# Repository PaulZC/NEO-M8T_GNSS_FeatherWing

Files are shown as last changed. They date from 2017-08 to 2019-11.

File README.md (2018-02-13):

# NEO-M8T GNSS FeatherWing

A clone of the [Adafruit Ultimate GPS FeatherWing](https://www.adafruit.com/product/3133) but with the u-blox NEO-M8T replacing the GlobalTop FGPMMOPA6H. The NEO-M8T can receive signals from GPS, Galileo and GLONASS or BeiDou concurrently and supports both SBAS and QZSS.
It also provides Multi-GNSS Raw Measurement (RAWX) Data which can be used for Post-Processed Kinematic (PPK) positioning.

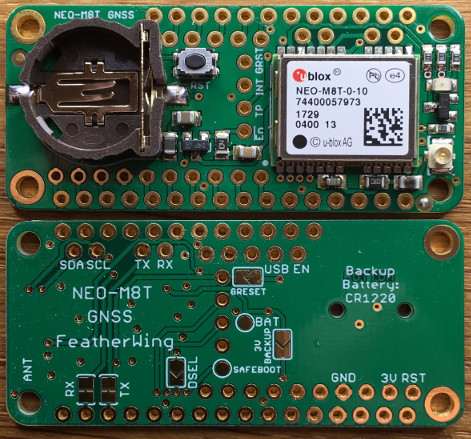
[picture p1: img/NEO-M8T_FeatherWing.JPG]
NEO-M8T_FeatherWing


**See [LEARN.md](https://github.com/PaulZC/NEO-M8T_GNSS_FeatherWing/blob/master/LEARN.md) for more details.**

[POST_PROCESS.md](https://github.com/PaulZC/NEO-M8T_GNSS_FeatherWing/blob/master/POST_PROCESS.md) contains results of a first time successful attempt at post-processed kinematic positioning using [rtkexplorer's demo5 version of RTKLIB](http://rtkexplorer.com/downloads/rtklib-code/).

See [NEO-M8T_GNSS_FeatherWing.pdf](https://github.com/PaulZC/NEO-M8T_GNSS_FeatherWing/blob/master/NEO-M8T_GNSS_FeatherWing.pdf) for the schematic, layout and Bill Of Materials.

The [Eagle](https://github.com/PaulZC/NEO-M8T_GNSS_FeatherWing/tree/master/Eagle) directory contains the schematic and pcb design files.

The [Arduino](https://github.com/PaulZC/NEO-M8T_GNSS_FeatherWing/tree/master/Arduino) directory contains code for the [Adafruit Feather M0 Adalogger](https://www.adafruit.com/products/2796) which will log RAWX data to SD card.

Distributed under a Creative Commons Attribution, Share-Alike license.

Enjoy!

**_Paul_**

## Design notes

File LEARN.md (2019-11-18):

# NEO-M8T GNSS FeatherWing

A clone of the [Adafruit Ultimate GPS FeatherWing](https://www.adafruit.com/product/3133) but with the u-blox NEO-M8T replacing the GlobalTop FGPMMOPA6H. The NEO-M8T can receive signals from GPS, Galileo and either GLONASS or BeiDou concurrently and supports both SBAS and QZSS.
It also provides Multi-GNSS Raw Measurement (RAWX) Data which can be used for Post-Processed Kinematic (PPK) positioning.

NEO-M8T_FeatherWing

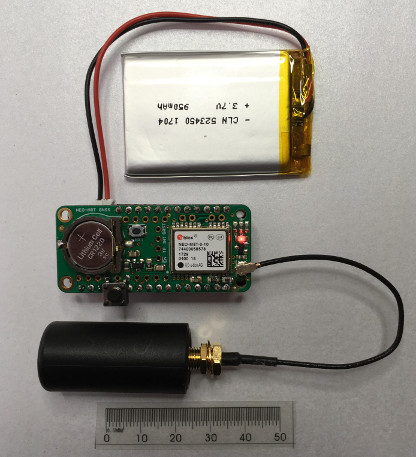
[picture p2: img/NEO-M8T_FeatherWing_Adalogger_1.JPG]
NEO-M8T_FeatherWing_Adalogger_1


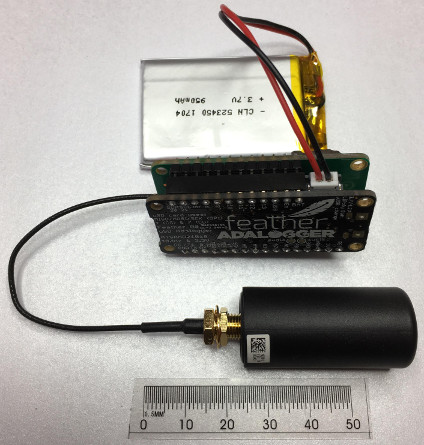
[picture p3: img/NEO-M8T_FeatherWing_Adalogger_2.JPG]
NEO-M8T_FeatherWing_Adalogger_2


See [NEO-M8T_GNSS_FeatherWing.pdf](https://github.com/PaulZC/NEO-M8T_GNSS_FeatherWing/blob/master/NEO-M8T_GNSS_FeatherWing.pdf) for the schematic, layout and Bill Of Materials.

The [Eagle](https://github.com/PaulZC/NEO-M8T_GNSS_FeatherWing/tree/master/Eagle) directory contains the schematic and PCB design files.

The [SMA_Antenna](https://github.com/PaulZC/NEO-M8T_GNSS_FeatherWing/tree/master/Eagle/SMA_Antenna) directory contains the schematic and PCB design files for an extended
version of the PCB which incorporates a robust SMA connector for the antenna instead of uFL.

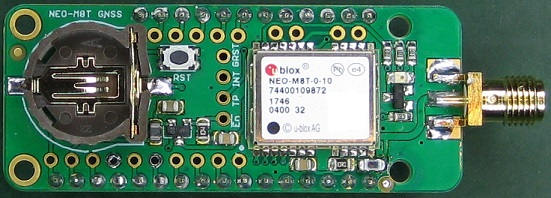
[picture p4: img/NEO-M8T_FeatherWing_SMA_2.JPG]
NEO-M8T_FeatherWing_SMA_2


The [Arduino](https://github.com/PaulZC/NEO-M8T_GNSS_FeatherWing/tree/master/Arduino) directory contains code for the [Adafruit Feather M0 Adalogger](https://www.adafruit.com/products/2796) which will log RAWX data to SD card.
- https://www.adafruit.com/products/2796
- https://learn.adafruit.com/adafruit-feather-m0-adalogger

[POST_PROCESS.md](https://github.com/PaulZC/NEO-M8T_GNSS_FeatherWing/blob/master/POST_PROCESS.md) contains results of a first time successful attempt at post-processed kinematic positioning using [rtkexplorer's demo5 version of RTKLIB](http://rtkexplorer.com/downloads/rtklib-code/).
Please refer to the [Precise Positioning Resources](https://github.com/PaulZC/NEO-M8T_GNSS_FeatherWing/blob/master/LEARN.md#precise-positioning-resources) for more information.

This guide concentrates on the differences between the NEO-M8T FeatherWing and the Adafruit Ultimate GPS FeatherWing. Please refer to Lady Ada's excellent documentation to get started with the Feather family and GPS:
- https://www.adafruit.com/product/3133
- https://learn.adafruit.com/adafruit-ultimate-gps-featherwing

## Power Pins

Like the Ultimate GPS FeatherWing, the NEO-M8T FeatherWing runs from +3.3V power and uses 3V logic. The NEO-M8T is powered directly from the 3V and GND pins on the bottom left of the Feather. Each Adafruit Feather has a regulator to provide clean 3V power from USB or battery power.

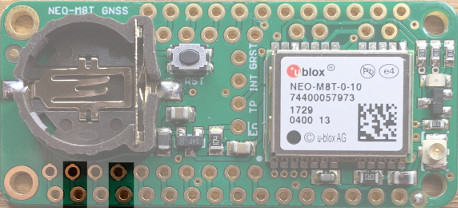
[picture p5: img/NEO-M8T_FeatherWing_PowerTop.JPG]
NEO-M8T_FeatherWing_PowerTop


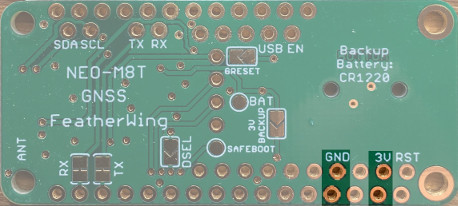
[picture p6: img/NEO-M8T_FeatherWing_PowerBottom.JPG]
NEO-M8T_FeatherWing_PowerBottom


If you want to completely power down the Adalogger _and_ the NEO-M8T, you can do this by pulling the Feather EN pin low (e.g. by connecting it to GND via a small slide switch).

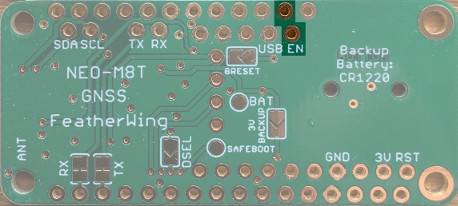
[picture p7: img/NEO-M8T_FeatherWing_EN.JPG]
NEO-M8T_FeatherWing_EN


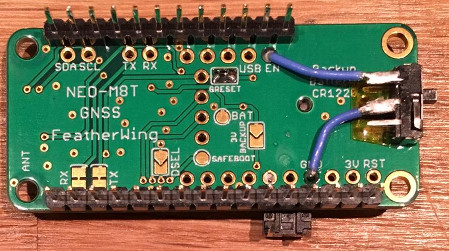
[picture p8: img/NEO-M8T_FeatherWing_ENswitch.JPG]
NEO-M8T_FeatherWing_ENswitch


## Serial Data Pins

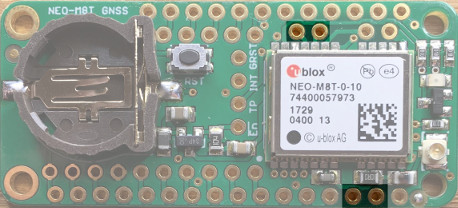
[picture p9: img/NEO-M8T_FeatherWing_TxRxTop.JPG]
NEO-M8T_FeatherWing_TxRxTop


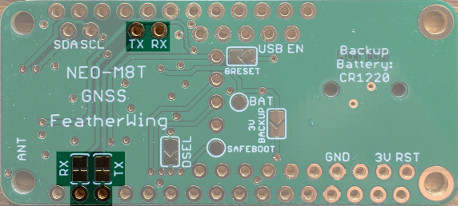
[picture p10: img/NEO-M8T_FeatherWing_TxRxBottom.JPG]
NEO-M8T_FeatherWing_TxRxBottom


The NEO-M8T FeatherWing, like the Ultimate GPS FeatherWing, can communicate over UART serial. It sends ASCII NMEA sentences from the TX pin to the microcontroller RX pin and can be controlled to change its data output from the microcontroller TX pin. Logic level is 3V for both.

The u-box M8 chipset also supports much more comprehensive UBX binary format messages (see [Serial Protocol](https://github.com/PaulZC/NEO-M8T_GNSS_FeatherWing/blob/master/LEARN.md#serial-protocol) below).

The baud rate by default is 9600 baud, but you can configure the module to use a different baud rate if desired. For RAWX logging you will need to use at least 115200 baud.

The NEO-M8T Tx and Rx pins are wired directly to the Serial pins at the bottom right of the Feather.
If you need to connect to a different set of pins, you can cut the RX and TX jumpers on the bottom of the board and connect instead to the TX and RX pads at the top of the board.

The ATSAMD21G18 ARM Cortex M0 chip on the Adalogger has multiple Sercom channels which can be used to provide additional serial ports, which is handy if you're already using Serial1 for something else:
- Adafruit: https://learn.adafruit.com/using-atsamd21-sercom-to-add-more-spi-i2c-serial-ports/creating-a-new-serial
- MartinL: https://forum.arduino.cc/index.php?topic=341054.msg2443086#msg2443086

## I2C Interface

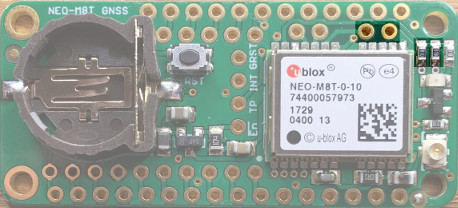
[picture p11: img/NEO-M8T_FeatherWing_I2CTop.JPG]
NEO-M8T_FeatherWing_I2CTop


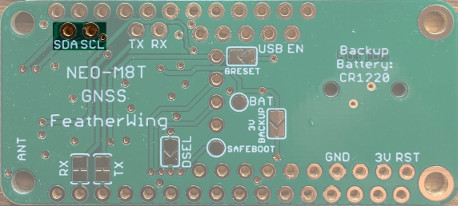
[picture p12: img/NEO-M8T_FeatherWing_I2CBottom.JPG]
NEO-M8T_FeatherWing_I2CBottom


The NEO-M8T also provides an I2C (DDC) interface. The SCL and SDA pins are broken out onto two pads near the top right corner of the board. Pull up resistors are provided (R5 & R6).

The SCL and SDA pads are not connected directly to SCL and SDA on the Adalogger. You will need to add your own jumper wires if you do want to make use of this interface.

## SPI Interface

The NEO-M8T SPI interface can be enabled by shorting the DSEL split pad:
- SDA becomes SPI CS
- SCL becomes SPI CLK
- TX becomes SPI MISO
- RX becomes SPI MOSI
- You may need to remove the SCL and SDA pull-up resistors (R5 & R6)
- You will need to cut the TX and RX jumpers to isolate the Adalogger Serial pins

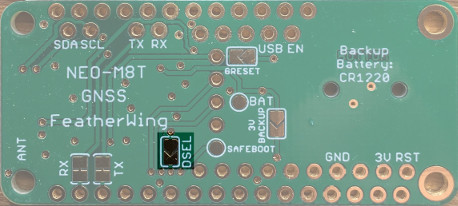
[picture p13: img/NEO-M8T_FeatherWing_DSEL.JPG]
NEO-M8T_FeatherWing_DSEL


## Reset Button

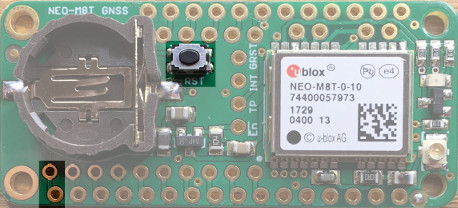
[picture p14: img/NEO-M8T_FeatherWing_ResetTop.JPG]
NEO-M8T_FeatherWing_ResetTop


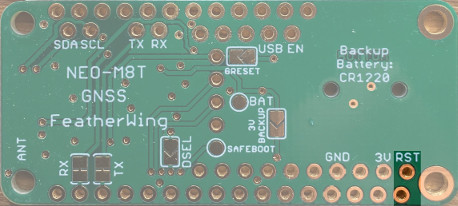
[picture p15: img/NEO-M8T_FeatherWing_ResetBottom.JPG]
NEO-M8T_FeatherWing_ResetBottom


There is a small button that will connect the microcontroller RESET pin to ground for resetting it. Handy to restart the Feather. Note that this is not connected to NEO-M8T reset unless you short the GRESET split pad on the rear of the PCB (see below).

## GNSS Breakout Pins

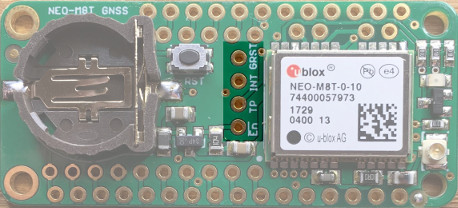
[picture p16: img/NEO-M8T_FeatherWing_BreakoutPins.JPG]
NEO-M8T_FeatherWing_BreakoutPins


**GRST** is connected to the NEO-M8T reset pin. You can reset the NEO-M8T by pulling this pin low. If you want to reset both the Feather _and_ the NEO-M8T via the reset button, short the GRESET split pad on the rear of the PCB.
Note that pulling GPS Reset low does not put the NEO-M8T into a low power state, you'll want to disable it instead (see En below).

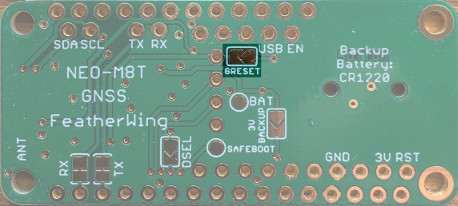
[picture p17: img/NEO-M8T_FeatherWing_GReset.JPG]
NEO-M8T_FeatherWing_GReset


**INT** is connected to the NEO-M8T EXTINT external interrupt pin. It can be used for control of the receiver or for aiding. See the [u-blox documentation links](https://github.com/PaulZC/NEO-M8T_GNSS_FeatherWing/blob/master/LEARN.md#datasheets) below for further details.

**TP** is connected to the NEO-M8T TP time pulse pin. It can be used to output pulse trains synchronized with GPS or UTC time grid with intervals configurable over a wide frequency range.
Thus it may be used as a low frequency time synchronization pulse or as a high frequency reference signal (up to 10 MHz). By default, the time pulse signal is configured to 1 pulse per second.

TP is also connected to an LED via a buffer transistor. By default it will flash once per second once the receiver is synchronised to GNSS time.

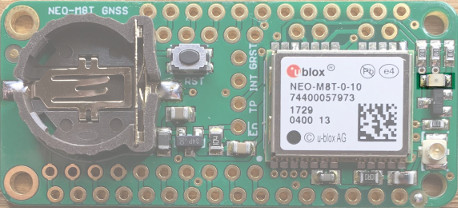
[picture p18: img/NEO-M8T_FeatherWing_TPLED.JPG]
NEO-M8T_FeatherWing_TPLED


**En** is a true 'power disable' control line you can use to completely cut power to the NEO-M8T. This is good if you need to run at ultra-low-power modes. By default this is pulled low (enabled). So pull high (to 3V) to disable the NEO-M8T.

## SAFEBOOT

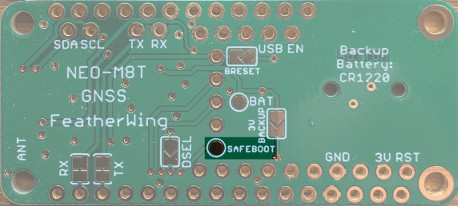
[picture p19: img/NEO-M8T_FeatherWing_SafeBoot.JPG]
NEO-M8T_FeatherWing_SafeBoot


The NEO-M8T SAFEBOOT pin is broken out on a test pad on the rear of the PCB. You will need access to this to update the firmware.

## Battery Backup

Like the Ultimate GPS FeatherWing, the NEO-M8T FeatherWing includes a holder for a CR1220 back-up battery which will keep the NEO-M8T's internal clock going if the power is removed or disabled, providing a much quicker "warm start" when the power is reconnected.

If you don't want to use the backup battery, you can instead draw backup power from the 3V pin by shorting the 3V BACKUP split pad. But be careful! Only do this if you **won't** be using the backup battery.
If you install the battery _and_ have the split pad shorted **BAD THINGS WILL HAPPEN!** You might want to put some tape over the battery holder if you have shorted the split pad.

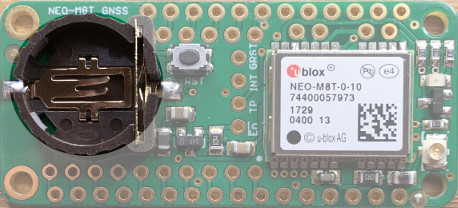
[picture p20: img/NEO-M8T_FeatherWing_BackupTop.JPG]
NEO-M8T_FeatherWing_BackupTop


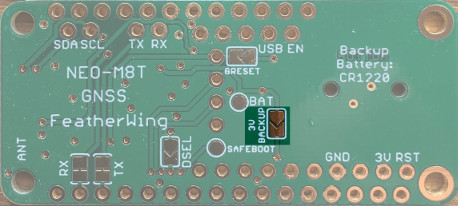
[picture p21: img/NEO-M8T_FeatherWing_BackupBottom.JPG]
NEO-M8T_FeatherWing_BackupBottom


## Antenna

The NEO-M8T needs to be connected to an external antenna via a uFL connector. 3V power for an active antenna is provided.

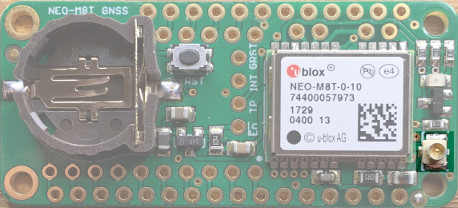
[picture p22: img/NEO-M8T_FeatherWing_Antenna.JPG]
NEO-M8T_FeatherWing_Antenna


The [SMA_Antenna](https://github.com/PaulZC/NEO-M8T_GNSS_FeatherWing/tree/master/Eagle/SMA_Antenna) directory contains the schematic and PCB design files for an extended
version of the PCB which incorporates a robust SMA connector for the antenna instead of uFL. The connector is Johnson part number 142-0711-821 (Farnell / Element 14 order code 1019328).

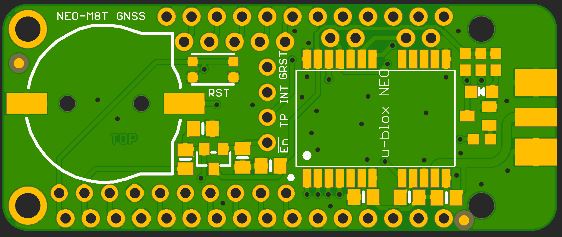
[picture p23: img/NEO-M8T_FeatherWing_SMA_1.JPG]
NEO-M8T_FeatherWing_SMA_1

NEO-M8T_FeatherWing_SMA_2

## Serial Protocol

The NEO-M8T is based on u-blox's sophisticated M8 chipset. By default it will output standard NMEA format navigation messages, but also supports much more comprehensive UBX binary format messages.
As the NEO-M8T is able to provide location information from GPS, GLONASS, Galileo and BeiDou you will find that the prefix of the NMEA messages changes to: $GP for GPS, SBAS and QZSS; $GL for GLONASS; $GA for Galileo; $GB for BeiDou; or $GN if it is using a mix of satellites (which is usually the case).
Having the messages prefixed with $GN will confuse the Adafruit GPS Library and Mikal Hart's TinyGPS. To get round this, you can force the "Talker ID" to GP by sending the following UBX binary format message:

- 0xb5, 0x62, 0x06, 0x17, 0x14, 0x00, 0x20, 0x40, 0x00, 0x02, 0x00, 0x00, 0x00, 0x00, 0x00, 0x01, 0x01, 0x01, 0x00, 0x00, 0x00, 0x00, 0x00, 0x00, 0x00, 0x00, 0x96, 0xd9

The M8 chipset supports several different navigation modes including: static, portable, pedestrian, automotive, sea and "Airborne <1G" (which is really useful for high altitude ballooning!).

By default, the NEO-M8T will receive signals from GPS, QZSS and GLONASS. If you want to enable Galileo and/or BeiDou reception, you'll need to do this with another UBX message (see below).

You can find the messages to change the navigation mode and GNSS configuration in the [RAWX_Logger](https://github.com/PaulZC/NEO-M8T_GNSS_FeatherWing/tree/master/Arduino/RAWX_Logger) Arduino code.

## RAWX_Logger

[RAWX_Logger](https://github.com/PaulZC/NEO-M8T_GNSS_FeatherWing/tree/master/Arduino/RAWX_Logger) is Arduino code written to run on the [Adafruit Feather M0 Adalogger](https://www.adafruit.com/products/2796).
- https://www.adafruit.com/products/2796
- https://learn.adafruit.com/adafruit-feather-m0-adalogger

Rover data is logged to a file called _r_hhmmss.ubx_, base (static) data is logged to a file called _b_hhmmss.ubx_. The code logs RAWX data continuously to SD card until the stop button is pressed.
Since the code is logging a large amount of data, it is necessary to keep the log file open throughout. If the power is removed or the board is reset before the stop button is pressed, the logged data will be lost.
Connect a normally-open push-to-close switch between swPin and GND. By default, swPin is Digital Pin 15 (0.2" away from the GND pin on the Adalogger). The pin can be changed by editing the code.

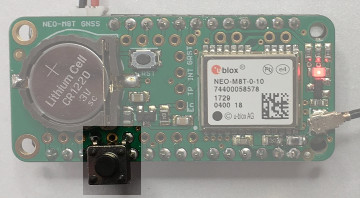
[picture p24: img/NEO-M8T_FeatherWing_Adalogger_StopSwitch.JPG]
NEO-M8T_FeatherWing_Adalogger_StopSwitch


[RAWX_Logger_2](https://github.com/PaulZC/NEO-M8T_GNSS_FeatherWing/tree/master/Arduino/RAWX_Logger_2) is an improved version of the logger.
A new log file is automatically opened every _INTERVAL_ minutes to: minimise data loss in the event of a power failure; and keep the file size manageable.
RAWX_Logger_2 pauses the GNSS RAWX messages while one file is closed and another opened, incurring a data loss of one or two RAWX messages.

In [RAWX_Logger_3](https://github.com/PaulZC/NEO-M8T_GNSS_FeatherWing/tree/master/Arduino/RAWX_Logger_3), a new log file is automatically opened every
_INTERVAL_ minutes, but the GNSS RAWX messages are _not_ paused while one file is closed and another opened, to allow contiguous data capture with no missing messages.
This technique is completely reliant on the serial receive buffer being large enough to store the incoming RAWX data between files.
In the unlikely event of a UBX checksum error or a loss of sync: the RAWX messages are paused, a new log file is opened, and then the RAWX messages are restarted.

In [RAWX_Logger_4](https://github.com/PaulZC/NEO-M8T_GNSS_FeatherWing/tree/master/Arduino/RAWX_Logger_4), serial data is automatically diverted into a large
RingBufferN by a timer interrupt, which means you do not need to increase the size of the serial receive buffer (by editing RingBuffer.h). Version 4 also includes NeoPixel support
making it easier to tell what the code is doing. The NeoPixel and LEDs can be disabled if the need the logger to be blacked out.

By default, RAWX data is logged every 250 msec (4Hz). This can be slowed down by selecting an alternate CFG-RATE message.

By default, the code will log raw measurements from GPS + Galileo + GLONASS + SBAS. This can be changed to GPS + Galileo + BeiDou + SBAS by commenting out the line which says _#define GLONASS_

By default, the code will use the static navigation mode. The chosen mobile (roving) mode can be selected by commenting out the line which says _#define STATIC_

The code now calculates the UBX checksum bytes for you, so it is much easier to make changes to the GNSS configuration. See sendUBX() in the code.

For RAWX_Logger, RAWX_Logger_2 and RAWX_Logger_3, you will need to increase the size of the serial receive buffer to avoid data overruns while data is being written to the SD card. See this post by MartinL:
- https://forum.arduino.cc/index.php?topic=365220.0

For the Adafruit Feather M0 Adalogger (SAMD), under Windows, edit:
- C:\Users\ ...your_user... \AppData\Local\Arduino15\packages\adafruit\hardware\samd\1.0.19\cores\arduino\RingBuffer.h

and change this line:
- #define SERIAL_BUFFER_SIZE 164

For RAWX_Logger, change it to:
- #define SERIAL_BUFFER_SIZE 2048

For RAWX_Logger_2 and RAWX_Logger_3, change it to:
- #define SERIAL_BUFFER_SIZE 8192

RAWX_Logger_4 uses a large RingBufferN to store the data. You do not need to edit RingBuffer.h if you use RAWX_Logger_4.

If you do edit RingBuffer.h, check the reported freeMemory before and after to make sure the change has been successful. (You should find that you've lost twice as much memory as expected!)

The code uses: the Adafruit GPS Library; Bill Greiman's SdFat; and Michael P. Flaga's MemoryFree. 
For RAWX_Logger_2, RAWX_Logger_3 and RAWX_Logger_4, you will also need the Arduino Real Time Clock library for the M0 (Arduino Zero).
See below for the download links.

## PC Logging

To log the RAWX data to file on a PC (instead of the Adalogger SD card):
- The [UBX_Echo](https://github.com/PaulZC/NEO-M8T_GNSS_FeatherWing/tree/master/Arduino/UBX_Echo) directory contains Arduino code for the Adalogger which will change the NEO-M8T Baud rate to 115200 and then echo all data to the PC.
- [NEO-M8T_GNSS_RAWX_Logger.py](https://github.com/PaulZC/NEO-M8T_GNSS_FeatherWing/blob/master/Python/NEO-M8T_GNSS_RAWX_Logger.py) is Python code which configures the NEO-M8T and then logs the RAWX data to file on a PC.
- [UBX_Checker.py](https://github.com/PaulZC/NEO-M8T_GNSS_FeatherWing/blob/master/Python/UBX_Checker.py) is Python code which can be used to check the integrity of the RAWX file (to make sure no data has been lost).

Hidden in [NEO-M8T_GNSS_RAWX_Logger.py](https://github.com/PaulZC/NEO-M8T_GNSS_FeatherWing/blob/master/Python/NEO-M8T_GNSS_RAWX_Logger.py) is code which calculates the UBX message checksums.

## Precise Positioning Resources

Useful precise positioning resources can be found at:
- https://rtklibexplorer.wordpress.com
- http://rtkexplorer.com/
- http://www.rtklib.com
- https://github.com/tomojitakasu/RTKLIB

## Datasheets

Useful documentation about the NEO-M8T and its protocol specification can be found at:
- [NEO-LEA-M8T-FW3_ProductSummary](https://www.u-blox.com/sites/default/files/products/documents/NEO-LEA-M8T-FW3_ProductSummary_%28UBX-16000801%29.pdf)
- [NEO-LEA-M8T-FW3_DataSheet](https://www.u-blox.com/sites/default/files/NEO-LEA-M8T-FW3_DataSheet_%28UBX-15025193%29.pdf)
- [NEO-8Q-NEO-M8-FW3_HardwareIntegrationManual](https://www.u-blox.com/sites/default/files/NEO-8Q-NEO-M8-FW3_HardwareIntegrationManual_%28UBX-15029985%29.pdf)
- [u-blox8-M8_ReceiverDescrProtSpec](https://www.u-blox.com/sites/default/files/products/documents/u-blox8-M8_ReceiverDescrProtSpec_%28UBX-13003221%29_Public.pdf)
- [CadSoft-Eagle-Library](https://github.com/u-blox/CadSoft-Eagle-Library.git)

## Adafruit GPS Library for Arduino

- https://github.com/adafruit/Adafruit-GPS-Library/

## Bill Greiman's SdFat

- https://github.com/greiman/SdFat

## Michael P. Flaga's MemoryFree

- https://github.com/mpflaga/Arduino-MemoryFree

## Arduino Real Time Clock library for the M0

- https://github.com/arduino-libraries/RTCZero

## Acknowledgements

The NEO-M8T GNSS FeatherWing is based extensively on an original design by Adafruit Industries:
- https://github.com/adafruit/Adafruit-Ultimate-GPS-FeatherWing-PCB

Distributed under a Creative Commons Attribution, Share-Alike license

Adafruit invests time and resources providing this open source design, please support Adafruit and open-source hardware by purchasing products from Adafruit!

Enjoy!

### _Paul_

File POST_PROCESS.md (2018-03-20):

# Initial attempts at Post-Processed Kinematic Positioning using the NEO-M8T GNSS FeatherWing

## 2017-09-17

It has been a great weekend! After populating the first two NEO-M8T GNSS FeatherWing PCBs last weekend,
this weekend I found time to give them a try and see if they showed any signs of delivering sub-cm accuracy post-processed kinematic positioning.

**The early signs are very encouraging!**

I'm very grateful to rtklibexplorer for this post:
- https://rtklibexplorer.wordpress.com/2017/08/25/online-rtklib-post-processing-demo-service/  

and for offering his demo service for free. What a guy.

### The Base Logger

The Base Logger is a NEO-M8T GNSS FeatherWing mounted on an Adafruit Feather M0 Adalogger, connected to the GPS-half of a
[Iridium Beam Whip Dual Mode Antenna RST706](https://www.beamcommunications.com/products/70-iridium-beam-whip-dual-mode-antenna)
which is mounted on the study roof with a reasonable view of the sky.

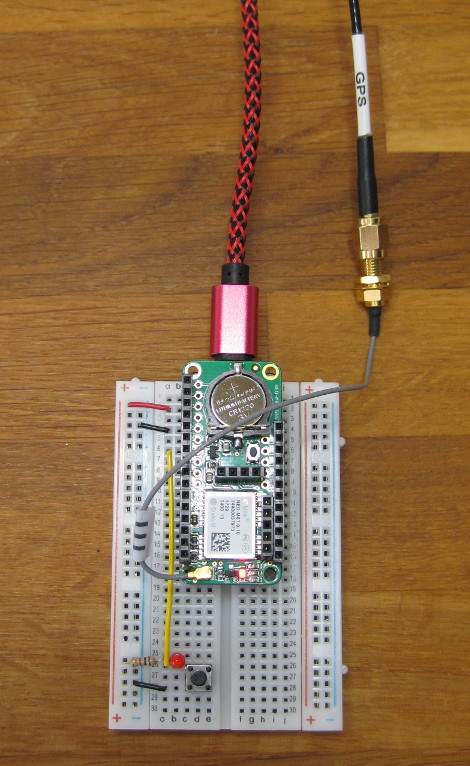
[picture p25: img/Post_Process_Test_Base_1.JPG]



The NEO-M8T is set to "Static" navigation mode by the Arduino code. See [LEARN.md](https://github.com/PaulZC/NEO-M8T_GNSS_FeatherWing/blob/master/LEARN.md) for more details.

### The Rover Logger

The Rover Logger is a second NEO-M8T GNSS FeatherWing mounted on another Adafruit Feather M0 Adalogger, powered by a 1000mAh LiPo battery,
connected to a passive helical antenna _with no ground plane_. The logger assembly is then mounted on the end of a rotating arm whirligig.




The NEO-M8T is set to "Portable" navigation mode by the Arduino code.

The antenna is positioned at a radius of 1m from the pivot. I think the position is accurate to a mm or so.

The antenna (and logger) rotate at approx. 22 revs per minute, or 2.3 m/s (5.1 mph). There's a video of it doing its thing here:
- https://github.com/PaulZC/NEO-M8T_GNSS_FeatherWing/blob/master/img/Post_Process_Mobile.mpeg

### The Arduino Code

I had a lightbulb moment earlier today when I realised that the loggers need to log RXM-SFRBX and TIM-TM2 messages in addition to RXM-RAWX.
Once I figured that out, everything dropped into place.

The updated [RAWX_Logger](https://github.com/PaulZC/NEO-M8T_GNSS_FeatherWing/tree/master/Arduino/RAWX_Logger) Arduino code logs these messages to SD card four times per second.

### rtklibexplorer's rtklib-post-processing-demo-service

Once I'd collected 15 minutes' worth of data from base and rover, the only thing I needed to do was change the filenames:
- Base:  from 20170917\183829.bin to base_20170917_183829.ubx
- Rover: from 20170917\183928.bin to rov_20170917_183928.ubx

I attached these files to an email, with the subject "rtklib demo", and sent it off to rtklibexplorer as per the instructions in the [blog post](https://rtklibexplorer.wordpress.com/2017/08/25/online-rtklib-post-processing-demo-service/).
Minutes later the analysis came back:

Base Observations:



Rover Observations:



Position Solution computed with the demo5 B28b version of RTKLIB. Yellow represents a float solution and green is a fixed solution:



Clearly I've got some more work to do, but that certainly looks like a 1m radius circle to me!

## 2017-09-24

Following on from [last week's update](https://github.com/PaulZC/NEO-M8T_GNSS_FeatherWing/blob/master/POST_PROCESS.md#2017-09-17),
I decided to download [rtkexplorer's demo5 version of RTKLIB](http://rtkexplorer.com/downloads/rtklib-code/) so I could run RTKLIB locally on my machine
rather than pester rtklibexplorer via the [demo service](https://rtklibexplorer.wordpress.com/2017/08/25/online-rtklib-post-processing-demo-service/).
I downloaded version B28a, but I see that version B29 has just been released.

I'm using Windows 10 Pro 64-bit and the executables ran straight out of the box.

To start, I used RTKCONV (rtkconv.exe) to convert the raw u-blox files from the base and rover loggers into RINEX format:



I changed the data format setting to _u-blox_, then changed the _Options_ to:



Then I converted first the base data (base_20170917_183829.ubx) and then the rover data (rov_20170917_183928.ubx).
This created the .nav and .obs files needed by RTKPOST.

Next I ran RTKPOST (rtkpost.exe):



I changed the _Options_ to:






I set:
- the _RINEX OBS: Rover_ file to the _rov .obs_ file created by RTKCONV
- the _RINEX OBS: Base Station_ file to the _base .obs_ file created by RTKCONV
- the _RINEX NAV/CLK_ file to the _rov .nav_ file created by RTKCONV

After pressing _Execute_ and then _Plot_, this is what I ended up with:



So far so good. I then changed the Filter Type setting to _Combined_ so the data is processed both forwards and backwards in time:



**_Hey presto!_** I ended up with this:



Now, that really does look like a very clean 1m radius circle. Perfect!

Analysing the data using least squares circle fitting shows that the radius is indeed very close to 1m:





The Python least squares circle fitting code is experimental and is based extensively on work done by [Miki at Meshlogic](https://meshlogic.github.io/posts/jupyter/curve-fitting/fitting-a-circle-to-cluster-of-3d-points/).
You can find a copy of [CSV_Circle_Fitting.py](https://github.com/PaulZC/NEO-M8T_GNSS_FeatherWing/blob/master/Python/CSV_Circle_Fitting.py) in the Python directory.
You will also need [POS_to_CSV.py](https://github.com/PaulZC/NEO-M8T_GNSS_FeatherWing/blob/master/Python/POS_to_CSV.py) to convert the .pos file produced by RTKPOST into a simple .csv file containing only the x,y,z ECEF coordinates of data points with a Q of 1.

## 2017-09-30

A simple analysis of the minimum positional error from each data point to the fitting circle shows: a mean of 8.8mm; a standard deviation of 5.4mm; and a worst case error of 3.3cm. Now that's a very pleasing result!



Enjoy!

**_Paul_**

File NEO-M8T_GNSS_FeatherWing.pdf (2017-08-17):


17/08/2017 07:31 \\thunderbird\home\pclark\Documents\eagle\NEO-M8T_GNSS_FeatherWing\NEO-M8T GNSS FeatherWing.sch (Sheet: 1/1)

Name | X | Y | Angle | Package | Value | Farnell /
Element 14 Comments
FID1 | 1.65 | 16.89 | 0 | FIDUCIAL | 1MM
FID2 | 46.51 | 1.06 | 0 | FIDUCIAL | 1MM
B1 | 10.38 | 12.83 | 0 | CR1220 Holder | | 2064722 | e.g. Multicomp CH291-1220LF
C1 | 27.01 | 6.54 | 180 | 0805 | 0.1uF | 2496944 | e.g. Walsin 0805B104K500CT
C2 | 20.19 | 10.29 | 0 | 0805 | 10uF | 2496998 | e.g. Walsin 0805F106Z100CT
C3 | 36.38 | 3.41 | 180 | 0805 | 10nF | 2496939 | e.g. Walsin 0805B103K500CT
FB1 | 18.41 | 7.22 | 90 | 0805 | Ferrite | 1635734 | e.g. Wurth Elektronik 742792031 (300R @ 100MHz)
L1 | 44.74 | 3.33 | 0 | 0805 | 27nH | 2286463 | e.g. Coilcraft 0805HT-27NTGLB
LED1 | 48.26 | 14.01 | 90 | 0805 (2.0x1.25) RED | 1716768 | e.g. Multicomp OVS-0808
Q1 | 21.28 | 7.24 | 180 | SOT23-WIDE | DMG3415U-7 1843688 | e.g. Diodes Inc DMG3415U-7
Q2 | 48.18 | 11.6 | 90 | SOT23-BEC | 2N2222 | 9846700 | e.g. Fairchild MMBT2222A
R1 | 49.68 | 17.04 | 270 | 0603 | 470R | 2447374 | e.g. Multicomp MCWR06X4700FTL
R2 | 24.19 | 7.37 | 90 | 0805 | 100K | 9333738 | e.g. Multicomp MC01W08055100K
R3 | 48.3 | 9.22 | 0 | 0603 | 1K | 2447272 | e.g. Multicomp MCWR06X1001FTL
R4 | 41.01 | 3.4 | 180 | 0805 | 10 ohm | 9332421 | e.g. Multicomp MC01W0805110R
R5 | 46.65 | 17.04 | 270 | 0603 | 1K | 2447272 | e.g. Multicomp MCWR06X1001FTL
R6 | 48.16 | 17.04 | 270 | 0603 | 1K | 2447272 | e.g. Multicomp MCWR06X1001FTL
SW1 | 21.21 | 16.26 | 180 | 4.6x2.8 | | 1605470 | e.g. Multicomp MCIPTG23K-V
U1 | 37.67 | 11.33 | 270 | NEO-M8T | NEO-M8T | https://www.u-blox.com/en/product/neolea-m8t-series
X1 | 47.63 | 6.24 | 180 | U.FL | uFL | 3908021 | e.g. Hirose U.FL-R-SMT(01)

Extras

B1 | | | | CR1220 | 3V Lithium | 2065165 | e.g. Multicomp CR1220
uFL to SMA Adaptor | 2448785 | e.g. RF Solutions CBA-UFLSMA-1

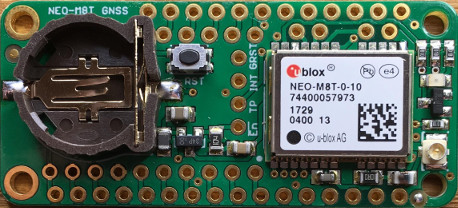
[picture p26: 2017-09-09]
img/NEO-M8T_FeatherWing_Top.JPG

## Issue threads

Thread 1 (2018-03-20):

Where to buy

fgnievinski, 2018-03-20:
Hi.  Your project seems to be the best hardware option for GPS post-processed kinematic (PPK) projects.  I use the Adalogger in other projects and they are really handy.  I used to use another product from CSG Shop [here](http://www.csgshop.com/product.php?id_product=205) but it requires a laptop or smartphone to log the data, which is not very practical in the field.  Then there is Tim Everett's Pi Logger [here](http://rtkexplorer.com/pi-zero-based-gps-data-logger/), which requires some configuration and more soldering.  Your project is the closest to plug-and-play that I've found so far (I maintain a wiki list [here](https://wiki.openstreetmap.org/wiki/RTKLIB-compatible_GPS_devices#Vendors)).  Now, I'm not familiar with PCBs and EAGLE to manufacture your design.  So I thought I'd ask if you'd consider selling these boards? Or maybe you know of a shop who'd be interested in offering this kind of service?  Thanks for your time and effort. PS: I'm a land surveyor.

PaulZC, 2018-03-20:
Hi there,
Thank you for your message.
Please contact me via the following link and we'll continue the discussion off-line:
https://www.dur.ac.uk/contactperson/?lid=1724
Best wishes,
Paul

Closed 2018-03-20.

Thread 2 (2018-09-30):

error in compiling RAWX_logger3

caris2010, 2018-09-30:
error
#include <Adafruit_GPS.h>
Am I missing something ?

caris2010, 2018-09-30:
sorry I forget to copy Adafruit library
but
still error
#include <RTCZero.h> // M0 Real Time Clock

PaulZC, 2018-10-01:
Hi,
Apologies!
For RAWX_Logger_2 and RAWX_Logger_3, you will also need the Arduino Real Time Clock library for the M0 (Arduino Zero):
https://github.com/arduino-libraries/RTCZero
I have updated both sketches and LEARN.md.
Best wishes,
Paul
https://www.dur.ac.uk/contactperson/?lid=1724

PaulZC, 2018-10-01:
Hi,
Yes, the Feather M0 Adalogger plus the NEO-M8T FeatherWing is completely self-contained. It does not need to be connected to a laptop, or need rtknav.
It will keep logging the RAWX data direct to the SD card until you press the stop button. In RAWX_Logger_3, a new file is opened every 15 minutes, but you can change this by editing the "Interval" in the code. If you want all the data to go into a single file, then RAWX_Logger_1 will do that.
After you have collected enough data, you can copy the base and rover files off the SD cards and process them with RTKCONV and RTKPOST:
https://github.com/PaulZC/NEO-M8T_GNSS_FeatherWing/blob/master/POST_PROCESS.md
I will be away for the rest of the week. If you have more questions, it may take me a few days to answer. Please use this link if you need to email me:
https://www.dur.ac.uk/contactperson/?lid=1724
Best wishes,
Paul

caris2010, 2018-10-02:
dear Paul
sorry to say that  still no Luck
Problem with RTCZero
Arduino: 1.8.7 (Windows 10), Board: "Adafruit Feather M0"

sketch\RAWX_Logger_3.ino.cpp.o: In function
`__static_initialization_and_destruction_0':
E:\gpss_tes\logger_ardu\RAWX_Logger_3/RAWX_Logger_3.ino:110: undefined
reference to `RTCZero::RTCZero()'
sketch\RAWX_Logger_3.ino.cpp.o: In function `loop':
E:\gpss_tes\logger_ardu\RAWX_Logger_3/RAWX_Logger_3.ino:500: undefined
reference to `RTCZero::begin(bool)'
E:\gpss_tes\logger_ardu\RAWX_Logger_3/RAWX_Logger_3.ino:501: undefined
reference to `RTCZero::setTime(unsigned char, unsigned char, unsigned char)'
E:\gpss_tes\logger_ardu\RAWX_Logger_3/RAWX_Logger_3.ino:502: undefined
reference to `RTCZero::setDate(unsigned char, unsigned char, unsigned char)'
E:\gpss_tes\logger_ardu\RAWX_Logger_3/RAWX_Logger_3.ino:503: undefined
reference to `RTCZero::setAlarmSeconds(unsigned char)'
E:\gpss_tes\logger_ardu\RAWX_Logger_3/RAWX_Logger_3.ino:506: undefined
reference to `RTCZero::setAlarmMinutes(unsigned char)'
E:\gpss_tes\logger_ardu\RAWX_Logger_3/RAWX_Logger_3.ino:507: undefined
reference to `RTCZero::enableAlarm(RTCZero::Alarm_Match)'
E:\gpss_tes\logger_ardu\RAWX_Logger_3/RAWX_Logger_3.ino:508: undefined
reference to `RTCZero::attachInterrupt(void (*)())'
E:\gpss_tes\logger_ardu\RAWX_Logger_3/RAWX_Logger_3.ino:561: undefined
reference to `RTCZero::getSeconds()'
E:\gpss_tes\logger_ardu\RAWX_Logger_3/RAWX_Logger_3.ino:562: undefined
reference to `RTCZero::getMinutes()'
E:\gpss_tes\logger_ardu\RAWX_Logger_3/RAWX_Logger_3.ino:563: undefined
reference to `RTCZero::getHours()'
E:\gpss_tes\logger_ardu\RAWX_Logger_3/RAWX_Logger_3.ino:564: undefined
reference to `RTCZero::getDay()'
E:\gpss_tes\logger_ardu\RAWX_Logger_3/RAWX_Logger_3.ino:565: undefined
reference to `RTCZero::getMonth()'
E:\gpss_tes\logger_ardu\RAWX_Logger_3/RAWX_Logger_3.ino:566: undefined
reference to `RTCZero::getYear()'
E:\gpss_tes\logger_ardu\RAWX_Logger_3/RAWX_Logger_3.ino:825: undefined
reference to `RTCZero::getSeconds()'
E:\gpss_tes\logger_ardu\RAWX_Logger_3/RAWX_Logger_3.ino:826: undefined
reference to `RTCZero::getMinutes()'
E:\gpss_tes\logger_ardu\RAWX_Logger_3/RAWX_Logger_3.ino:827: undefined
reference to `RTCZero::getHours()'
E:\gpss_tes\logger_ardu\RAWX_Logger_3/RAWX_Logger_3.ino:828: undefined
reference to `RTCZero::getDay()'
E:\gpss_tes\logger_ardu\RAWX_Logger_3/RAWX_Logger_3.ino:829: undefined
reference to `RTCZero::getMonth()'
E:\gpss_tes\logger_ardu\RAWX_Logger_3/RAWX_Logger_3.ino:830: undefined
reference to `RTCZero::getYear()'
E:\gpss_tes\logger_ardu\RAWX_Logger_3/RAWX_Logger_3.ino:860: undefined
reference to `RTCZero::getMinutes()'
E:\gpss_tes\logger_ardu\RAWX_Logger_3/RAWX_Logger_3.ino:863: undefined
reference to `RTCZero::setAlarmMinutes(unsigned char)'
E:\gpss_tes\logger_ardu\RAWX_Logger_3/RAWX_Logger_3.ino:966: undefined
reference to `RTCZero::getSeconds()'
E:\gpss_tes\logger_ardu\RAWX_Logger_3/RAWX_Logger_3.ino:967: undefined
reference to `RTCZero::getMinutes()'
E:\gpss_tes\logger_ardu\RAWX_Logger_3/RAWX_Logger_3.ino:968: undefined
reference to `RTCZero::getHours()'
E:\gpss_tes\logger_ardu\RAWX_Logger_3/RAWX_Logger_3.ino:969: undefined
reference to `RTCZero::getDay()'
E:\gpss_tes\logger_ardu\RAWX_Logger_3/RAWX_Logger_3.ino:970: undefined
reference to `RTCZero::getMonth()'
E:\gpss_tes\logger_ardu\RAWX_Logger_3/RAWX_Logger_3.ino:971: undefined
reference to `RTCZero::getYear()'
E:\gpss_tes\logger_ardu\RAWX_Logger_3/RAWX_Logger_3.ino:1103: undefined
reference to `RTCZero::getSeconds()'
E:\gpss_tes\logger_ardu\RAWX_Logger_3/RAWX_Logger_3.ino:1104: undefined
reference to `RTCZero::getMinutes()'
E:\gpss_tes\logger_ardu\RAWX_Logger_3/RAWX_Logger_3.ino:1105: undefined
reference to `RTCZero::getHours()'
E:\gpss_tes\logger_ardu\RAWX_Logger_3/RAWX_Logger_3.ino:1106: undefined
reference to `RTCZero::getDay()'
E:\gpss_tes\logger_ardu\RAWX_Logger_3/RAWX_Logger_3.ino:1107: undefined
reference to `RTCZero::getMonth()'
E:\gpss_tes\logger_ardu\RAWX_Logger_3/RAWX_Logger_3.ino:1108: undefined
reference to `RTCZero::getYear()'
collect2.exe: error: ld returned 1 exit status
exit status 1
Error compiling for board Adafruit Feather M0.

sorry for too long

Pada tanggal Sen, 1 Okt 2018 pukul 17.41 Paul <notifications@github.com>
menulis:

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

PaulZC, 2018-10-02:
Hi Catur,
It looks like you might not have the RTCZero library installed correctly?
You can download the RTCZero library as a zip file by going to:
https://github.com/arduino-libraries/RTCZero
then click "Clone or Download" and then click "Download ZIP".
Please see the instructions at:
https://www.arduino.cc/en/Guide/Libraries
Scroll down to "Importing a .zip Library" or "Manual installation" and follow the instructions there.
Afterwards, if you look in your "Arduino" directory, then go into your "libraries" sub-directory, you should then see a sub-sub-directory called "RTCZero" which has the source code for the library inside?
Best wishes,
Paul

caris2010, 2018-10-02:
ok Thank you
its working now
let try
good response Paul
Thank you again
ANyway... do you have a wiring diagrame or picture connection?

Pada tanggal Rab, 3 Okt 2018 pukul 02.30 Paul <notifications@github.com>
menulis:

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

PaulZC, 2018-10-04:
Hi Catur,

The schematic for the FeatheWing circuit board is here:
https://github.com/PaulZC/NEO-M8T_GNSS_FeatherWing/blob/master/NEO-M8T_GNSS_FeatherWing.pdf

The easiest way to connect it to the Adalogger is to use "stacking headers":
https://learn.adafruit.com/adafruit-feather-m0-adalogger/pinouts
https://learn.adafruit.com/adafruit-feather-m0-adalogger/assembly
Solder stacking headers onto the Adalogger and standard male header strip on the FeatherWing
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
caris2010, 2018-10-10:
Sorry Paul

I found your that your work close to my interesting
I need to logger a raw data phase from ublox then make post processing.
Just like you have done
But I only have neo-m8T from csgshop and adalogger.. not featherwing
So.
1. Recently. I use smartphone as a logger data. and connect via bluetooth
with m8t. That is why I ask you about command ublox via bluetooth.. not
command from adafruit like you do

2. In the beginning, I just want to use adalogger as a logger on micro SD.
Then I do not need smartphone for logging. The smartphone just used in the
first time for sending command to make m8t  output raw data. But your code
have command also. So it make m8t working as small Geodetik receiver like..
this is great

3. About the stopp log button. Ia There any others way to make adalogger
close or stop then save the record without push button.. I am afraid could
be forgeted ini the field

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

On Oct 10, 2018 3:09 PM, "Paul" <notifications@github.com> wrote:

Hi Catur,
Can you describe your project in more detail? I'm having difficulty
understanding why you would want to configure the NEO-M8T using u-center
and then want to use the Adalogger to log the RAWX data?
The RAWX_Logger code uses the NMEA messages from the NEO-M8T to provide the
time and date for the log files and to set the Real Time Clock (for
RAWX_Logger_2 and RAWX_Loger_3). You will need to edit the code if you do
not want it to do this.
You can change the RAWX rate from 4Hz to 1Hz by changing the measurement
rate (interval) from 250msec to 1000msec:
Find the line which says:
"sendUBX(setRATE, len_setRATE); // Set Navigation/Measurement Rate"
and change it to:
"sendUBX(setRATE_1Hz, len_setRATE); // Set Navigation/Measurement Rate"
Best wishes,
Paul

—
You are receiving this because you authored the thread.
Reply to this email directly, view it on GitHub
<https://github.com/PaulZC/NEO-M8T_GNSS_FeatherWing/issues/2#issuecomment-428478606>,
or mute the thread
<https://github.com/notifications/unsubscribe-auth/AhFuQbV4vfOy4LpYHW6itqxhZie5eYnTks5ujas8gaJpZM4XA8sj>
.

PaulZC, 2018-10-10:
Hi Catur,
Thanks for the explanation.
RAWX_Logger_3 opens a new file every 15 minutes. You could change this to every 5 minutes. That way you would only lose 5 minutes of data at most if you forget to press the stop button.
The log file is closed at the exact end of a RAWX message, so you don’t lose any data. The files can easily be joined together to make one big file for processing with RTKlib.
Have fun!
Paul

caris2010, 2018-10-10:
Ok great
How can we combine the 5minute file to one big file?? Possible with
rtkconv??

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

PaulZC, 2018-10-12:
Hi Catur,
On Windows, you can merge the files using:
copy /b r_*.ubx rover.ubx
Run this in a Command Prompt (cmd) window.
The file names contain the time each file was opened, so copy will merge them in the correct order into a new file called rover.ubx.
Best wishes,
Paul

caris2010, 2018-10-12:
Thx Paul
Is there any empty data or loss record
In time between each file?
I mean is it possible there is a jump data record in last fille and the
bigening new file?

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

caris2010, 2018-10-12:
Oww.. great Paul
In Rawx_logger3 can I get 1 full record file also ? Or
only get splited file then merger all to one big record data file?

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

PaulZC, 2018-10-14:
Hi Catur,
RAWX_Logger (1) logs all of the data to a single file. But, if you forget to press the stop button, you will lose all your data.
At the moment, the FeatherWing board is not for sale. I made a few boards for our projects in Durham, but unfortunately I do not have time to make and sell more.
You can of course have your own boards made. The Eagle PCB files are here:
https://github.com/PaulZC/NEO-M8T_GNSS_FeatherWing/tree/master/Eagle
and the Bill Of Materials is here:
https://github.com/PaulZC/NEO-M8T_GNSS_FeatherWing/blob/master/NEO-M8T_GNSS_FeatherWing.pdf
Good luck!
Paul

caris2010, 2018-10-14:
Ok thank you

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

caris2010, 2018-10-15:
dear Paul
I mean..
in your logger_3 is it only save some separate 15min files or we can get a
full record file also ?

Pada tanggal Sen, 15 Okt 2018 pukul 02.41 Paul <notifications@github.com>
menulis:

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

PaulZC, 2018-10-15:
Hi Catur,
If you want only one log file, please use RAWX_Logger (1).
If you want 15 minute files, please use RAWX_Logger_3. You can join the files together into one big file using copy /b. No data is lost between one file and the next, you will still get all the data.
Please try running the code with your Adalogger and CSG Shop board and see what happens. We learn by trying things for ourselves, not by asking other people for the answers.
Best wishes,
Paul

caris2010, 2018-10-15:
Ok thanks and sorry

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

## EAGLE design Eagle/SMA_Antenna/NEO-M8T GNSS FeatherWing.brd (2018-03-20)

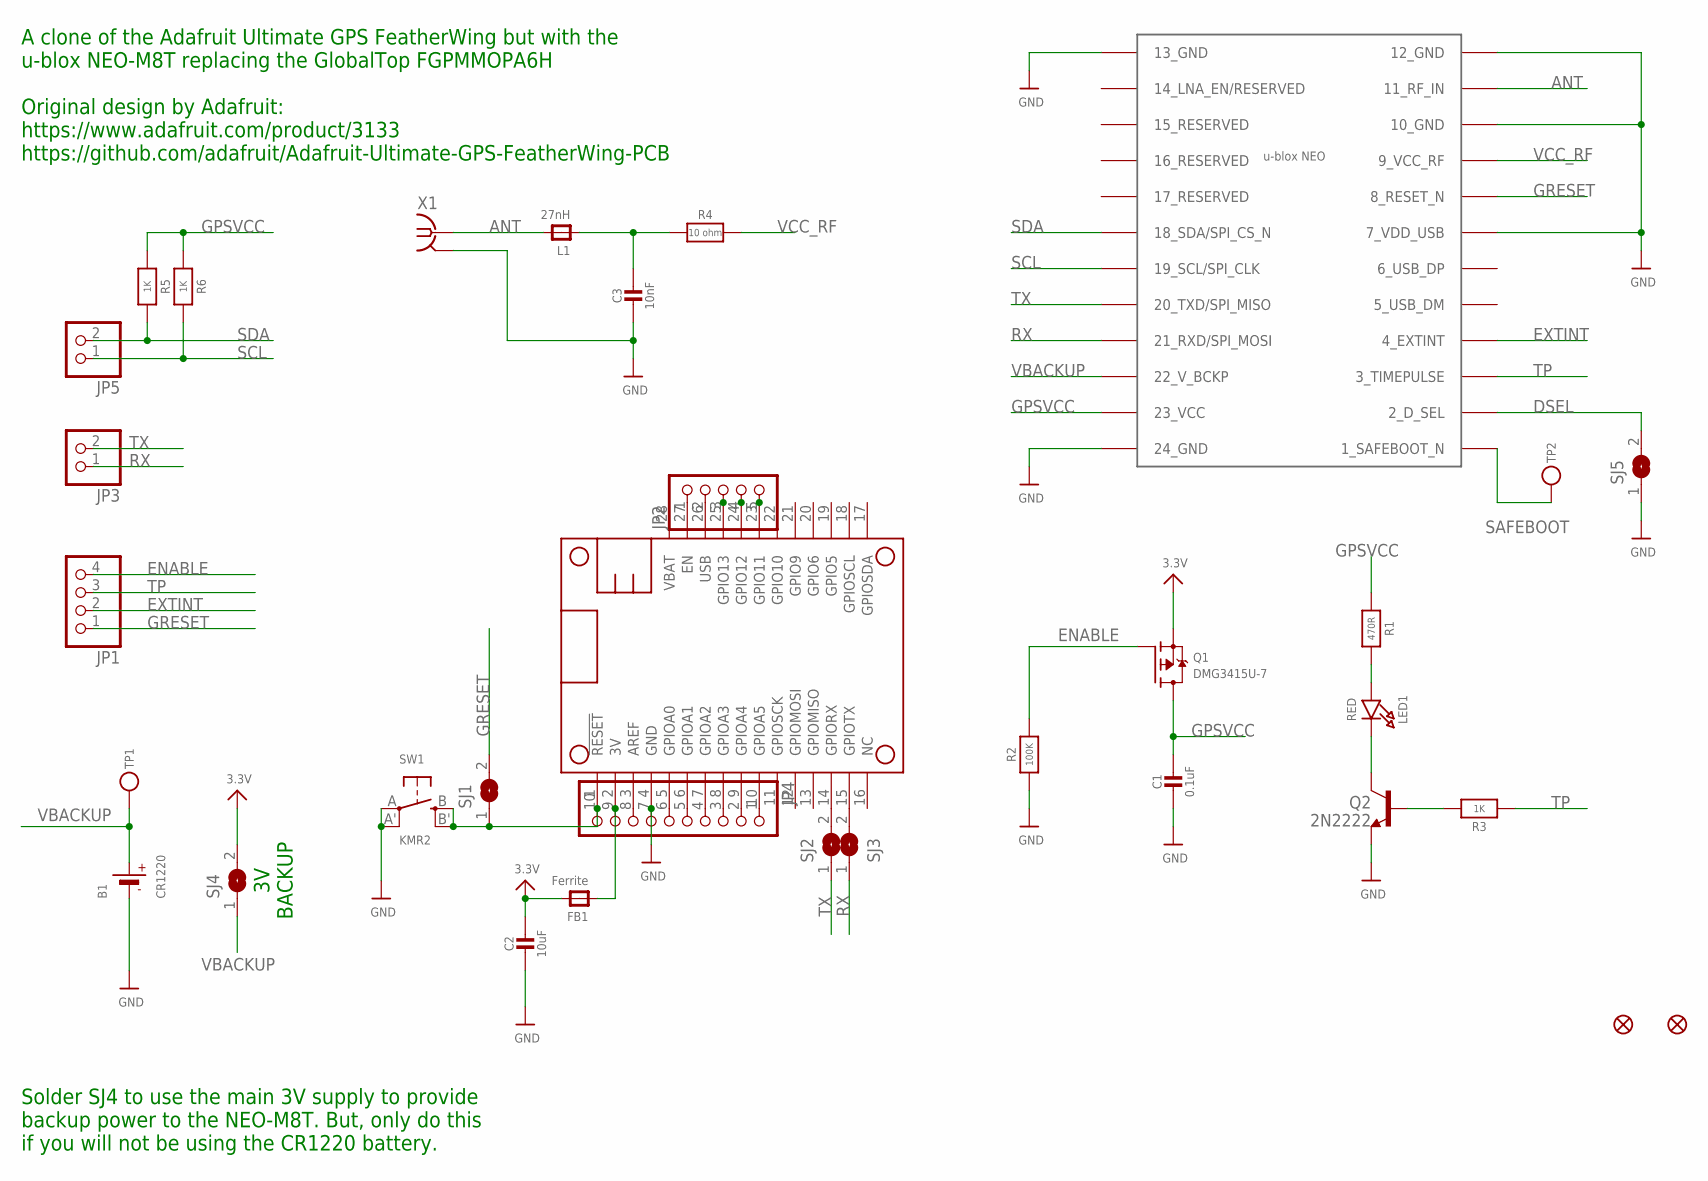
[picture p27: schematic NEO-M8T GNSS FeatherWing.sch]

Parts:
B1: CR1220; CR1220-2
C1: 0.1uF; 0805-NO
C2: 10uF; 0805-NO
C3: 10nF; 0805-NO
FB1: Ferrite; 0805-NO
FID1, FID2: FIDUCIAL""; FIDUCIAL_1MM
JP1: HEADER-1X4ROUND; 1X04_ROUND
JP2: HEADER-1X570MIL; 1X05_ROUND_70
JP3, JP5: HEADER-1X2ROUND; 1X02_ROUND
JP4: HEADER-1X10ROUND; 1X10_ROUND
L1: 27nH; 0805-NO
LED1: RED; CHIPLED_0805_NOOUTLINE
MS1: MICROBUILDER_FEATHERWINGSMA; MICROBUILDER_FEATHERWING_SMA
Q1: DMG3415U-7; SOT23-WIDE
Q2: 2N2222; SOT23-BEC
R1: 470R; 0603-NO
R2: 100K; 0805-NO
R3, R5, R6: 1K; 0603-NO
R4: 10 ohm; 0805-NO
SJ1, SJ4, SJ5: SOLDERJUMPER; SOLDERJUMPER_ARROW_NOPASTE
SJ2, SJ3: SOLDERJUMPERCLOSED; SOLDERJUMPER_CLOSEDWIRE
SW1: KMR2; BTN_KMR2_4.6X2.8
TP1, TP2: TESTPOINTROUND1.5MM; TESTPOINT_ROUND_1.5MM
U1: NEO-M8
X1: SMA-142-0711-821/826; J502-ND-142-0711-821/826

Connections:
3.3V: C2.1, FB1.2, Q1.2 (S), SJ4.2
3V: FB1.1, JP4.9, MS1.2 (3V)
ANT: L1.2, U1.11 (11_RF_IN), X1.1
DSEL: SJ5.2, U1.2 (2_D_SEL)
ENABLE: JP1.4, Q1.1 (G), R2.2
EXTINT: JP1.2, U1.4 (4_EXTINT)
GND: B1.-, C1.2, C2.2, C3.2, JP4.7, MS1.4 (GND), Q2.E, R2.1, SJ5.1, SW1.A, SW1.A' (P1), U1.7 (7_VDD_USB), U1.10 (10_GND), U1.12 (12_GND), U1.13 (13_GND), U1.24 (24_GND), X1.G@1 (2), X1.G@2 (2), X1.G@3 (2), X1.G@4 (2)
GPSVCC: C1.1, Q1.3 (D), R1.1, R5.1, R6.1, U1.23 (23_VCC)
GRESET: JP1.1, SJ1.2, U1.8 (8_RESET_N)
unnamed: JP2.3, MS1.25 (GPIO13)
unnamed: LED1.A, R1.2
unnamed: JP2.4, MS1.24 (GPIO12)
unnamed: C3.1, L1.1, R4.1
unnamed: JP2.5, MS1.23 (GPIO11)
unnamed: JP4.1, MS1.10 (GPIOA5)
unnamed: JP4.2, MS1.9 (GPIOA4)
unnamed: JP4.3, MS1.8 (GPIOA3)
unnamed: JP4.4, MS1.7 (GPIOA2)
unnamed: JP4.5, MS1.6 (GPIOA1)
unnamed: JP4.6, MS1.5 (GPIOA0)
unnamed: JP4.8, MS1.3 (AREF)
unnamed: JP2.1, MS1.27 (EN)
unnamed: MS1.14 (GPIORX), SJ2.2
unnamed: MS1.15 (GPIOTX), SJ3.2
unnamed: LED1.C, Q2.C
unnamed: Q2.B, R3.2
RST: JP4.10, MS1.1 (!RESET), SJ1.1, SW1.B (S), SW1.B' (S1)
RX: JP3.1, SJ3.1, U1.21 (21_RXD/SPI_MOSI)
SAFEBOOT: TP2.P$1, U1.1 (1_SAFEBOOT_N)
SCL: JP5.1, R6.2, U1.19 (19_SCL/SPI_CLK)
SDA: JP5.2, R5.2, U1.18 (18_SDA/SPI_CS_N)
TP: JP1.3, R3.1, U1.3 (3_TIMEPULSE)
TX: JP3.2, SJ2.1, U1.20 (20_TXD/SPI_MISO)
USB: JP2.2, MS1.26 (USB)
VBACKUP: B1.+, SJ4.1, TP1.P$1, U1.22 (22_V_BCKP)
VCC_RF: R4.2, U1.9 (9_VCC_RF)

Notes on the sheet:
A clone of the Adafruit Ultimate GPS FeatherWing but with the u-blox NEO-M8T replacing the GlobalTop FGPMMOPA6H Original design by Adafruit: https://www.adafruit.com/product/3133 https://github.com/adafruit/Adafruit-Ultimate-GPS-FeatherWing-PCB
3V BACKUP
Solder SJ4 to use the main 3V supply to provide backup power to the NEO-M8T. But, only do this if you will not be using the CR1220 battery.

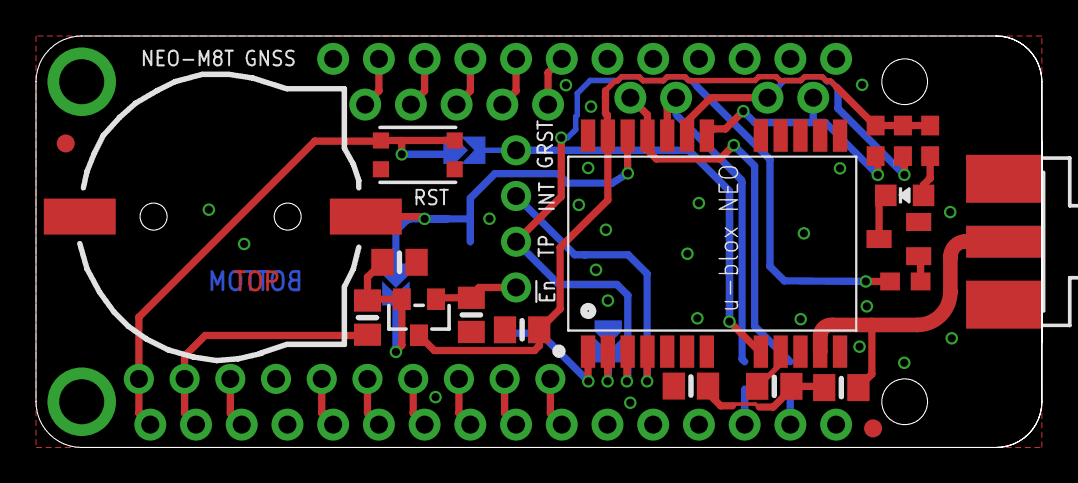
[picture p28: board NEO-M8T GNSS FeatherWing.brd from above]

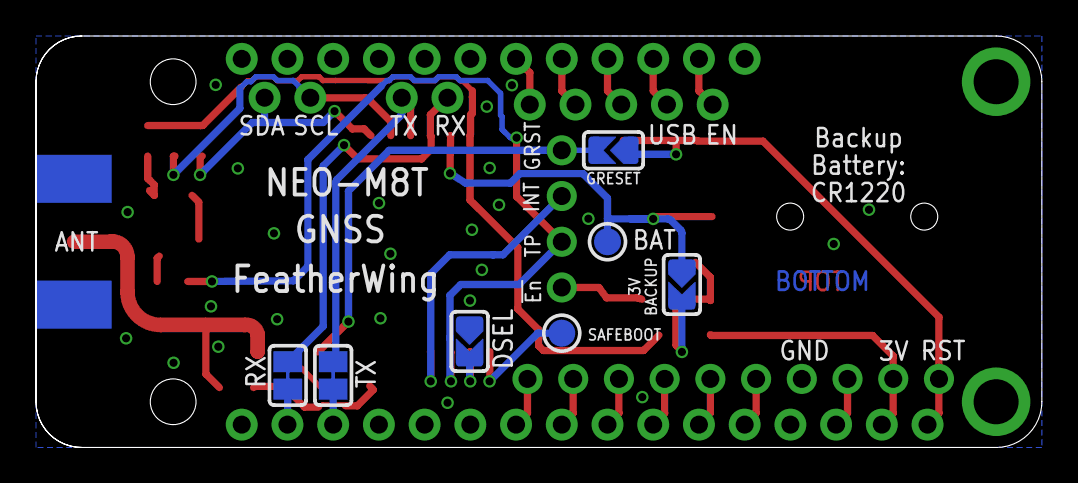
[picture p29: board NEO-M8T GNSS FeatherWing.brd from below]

Board: 2 copper layers, 55.9 x 22.9 mm, 33 parts (7 on the bottom side), 36 nets.

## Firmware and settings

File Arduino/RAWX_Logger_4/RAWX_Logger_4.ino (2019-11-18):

// RAWX_Logger V4

// Logs RXM-RAWX, RXM-SFRBX and TIM-TM2 data from u-blox NEO-M8T GNSS to SD card

// Changes to a new log file every INTERVAL minutes

// Version 4 uses a RingBufferN to store the incomming serial data so you don't need to worry about increasing
// the serial receive buffer size

// This version also includes NeoPixel support

// This code is written for the Adalogger M0 Feather
// https://www.adafruit.com/products/2796
// https://learn.adafruit.com/adafruit-feather-m0-adalogger

// GNSS data is provided by Paul's u-blox NEO-M8T FeatherWing
// https://github.com/PaulZC/NEO-M8T_GNSS_FeatherWing

// Solder the GRESET link so that pressing the reset button
// resets the NEO-M8T as well as the Adalogger.

// Choose a good quality SD card. Some cheap cards can't handle the write rate.
// Ensure the card is formatted as FAT32.

// The RAWX log file has a .ubx suffix instead of .bin
// The log filename starts with "r_" for the rover and "b_" for the static base

// Define how long we should log in minutes before changing to a new file
// Sensible values are: 5, 10, 15, 20, 30, 60
// Must be <= 60 (or RTC alarm code needs to be updated to match on HHMMSS)
const int INTERVAL = 15;

// Define how long we should wait in msec (approx.) for residual RAWX data before closing the last log file
// For a measurement rate of 4Hz (250msec), 300msec is a sensible value. i.e. slightly more than one measurement interval
const int dwell = 300;

// Define if this is the static base logger
//#define STATIC // Comment this line out for the mobile rover logger

// LEDs

//#define NoLED // Uncomment this line to completely disable the LEDs
//#define NoLogLED // Uncomment this line to disable the LEDs during logging only

// NeoPixel Settings
//#define NeoPixel // Uncomment this line to enable a NeoPixel on the same pin as RedLED

// The red LED flashes during SD card writes
#define RedLED 13 // The red LED on the Adalogger is connected to Digital Pin 13
// The green LED indicates that the GNSS has established a fix 
#define GreenLED 8 // The green LED on the Adalogger is connected to Digital Pin 8

// Support for the WB2812B NeoPixel is provided by Adafruit:
// https://github.com/adafruit/Adafruit_NeoPixel

#ifdef NeoPixel
#include <Adafruit_NeoPixel.h> // Support for the WB2812B
#define swap_red_green // Uncomment this line if your WB2812B has red and green reversed
#ifdef swap_red_green
  Adafruit_NeoPixel pixels = Adafruit_NeoPixel(1, RedLED, NEO_GRB + NEO_KHZ800); // GRB WB2812B
#else
  Adafruit_NeoPixel pixels = Adafruit_NeoPixel(1, RedLED, NEO_RGB + NEO_KHZ800); // RGB WB2812B
#endif
#define LED_Brightness 32 // 0 - 255 for WB2812B
#endif

// Define SerialBuffer as a large RingBuffer which we will use to store the Serial1 receive data
// Actual Serial1 receive data will be copied into SerialBuffer by a timer interrupt
// https://gist.github.com/jdneo/43be30d85080b175cb5aed3500d3f989
// That way, we do not need to increase the size of the Serial1 receive buffer (by editing RingBuffer.h)
RingBufferN<8192> SerialBuffer; // Define SerialBuffer as a RingBuffer of size 8192 bytes

// Define the GNSS configuration: GPS + Galileo + either GLONASS or BeiDou
#define GLONASS // Comment this line out to use BeiDou

// Send serial debug messages
//#define DEBUG // Comment this line out to disable debug messages

// Connect a normally-open push-to-close switch between swPin and GND.
// Press it to stop logging and close the log file.
#define swPin 15 // Digital Pin 15 (0.2" away from the GND pin on the Adalogger)

// Include the Adafruit GPS Library
// https://github.com/adafruit/Adafruit_GPS
// This is used at the start of the code to establish a fix and
// provide the date and time for the RAWX log file filename
#include <Adafruit_GPS.h>
Adafruit_GPS GPS(&Serial1); // M0 hardware serial
// Set GPSECHO to 'false' to turn off echoing the GPS data to the Serial console
// Set to 'true' if you want to debug and listen to the raw GPS sentences
#define GPSECHO false
// this keeps track of whether we're using the interrupt
// off by default!
boolean usingInterrupt = false;

// Fast SD card logging using Bill Greiman's SdFat
// https://github.com/greiman/SdFat
// From FatFile.h:
//   * \note Data is moved to the cache but may not be written to the
//   * storage device until sync() is called.

#include <SPI.h>
#include <SdFat.h>
const uint8_t cardSelect = 4; // Adalogger uses D4 as the SD SPI select
SdFat sd;
SdFile rawx_dataFile;
#ifdef STATIC
char rawx_filename[] = "20000000/b_000000.ubx"; // base logfile
#else
char rawx_filename[] = "20000000/r_000000.ubx"; // rover logfile
#endif
char dirname[] = "20000000";
long bytes_written = 0;

// Define packet size, buffer and buffer pointer for SD card writes
const size_t SDpacket = 512;
uint8_t serBuffer[SDpacket];
size_t bufferPointer = 0;
int numBytes;

// Michael P. Flaga's MemoryFree:
// https://github.com/mpflaga/Arduino-MemoryFree
#include <MemoryFree.h>;

// Battery voltage
float vbat;
#define LOWBAT 3.55 // Low battery voltage

#include <RTCZero.h> // M0 Real Time Clock
RTCZero rtc; // Create an rtc object
volatile bool alarmFlag = false; // RTC alarm (interrupt) flag

// Count number of valid fixes before starting to log
#define maxvalfix 10 // Collect at least this many valid fixes before logging starts
int valfix = 0;

// Loop Steps
#define init          0
#define start_rawx    1
#define open_file     2
#define write_file    3
#define new_file      4
#define close_file    5
#define restart_file  6
int loop_step = init;

// UBX State
#define looking_for_B5          0
#define looking_for_62          1
#define looking_for_class       2
#define looking_for_ID          3
#define looking_for_length_LSB  4
#define looking_for_length_MSB  5
#define processing_payload      6
#define looking_for_checksum_A  7
#define looking_for_checksum_B  8
#define sync_lost               9
int ubx_state = looking_for_B5;
int ubx_length = 0;
int ubx_class = 0;
int ubx_ID = 0;
int ubx_checksum_A = 0;
int ubx_checksum_B = 0;
int ubx_expected_checksum_A = 0;
int ubx_expected_checksum_B = 0;

// Definitions for u-blox M8 UBX-format (binary) messages
// The message definitions need to include the 0xB5 and 0x62 sync chars 
// The message definitions don't contain the checksum bytes - these are calculated and appended by sendUBX
// Each message needs to have a length defined

// Set Nav Mode to Static
static const uint8_t setNavStatic[] = {
  0xB5, 0x62, 0x06, 0x24, 0x24, 0x00, 0xFF, 0xFF, 0x02, 0x03, 0x00, 0x00, 0x00, 0x00, 0x10, 0x27, 0x00, 0x00, 
  0x05, 0x00, 0xFA, 0x00, 0xFA, 0x00, 0x64, 0x00, 0x5E, 0x01, 0x00, 0x00, 0x00, 0x00, 0x00, 0x00, 0x00, 0x00, 
  0x03, 0x00, 0x00, 0x00, 0x00, 0x00 };
static const int len_setNav = 42;

// Set Nav Mode to Portable
static const uint8_t setNavPortable[] = {
  0xB5, 0x62, 0x06, 0x24, 0x24, 0x00, 0xFF, 0xFF, 0x00, 0x03, 0x00, 0x00, 0x00, 0x00, 0x10, 0x27, 0x00, 0x00, 
  0x05, 0x00, 0xFA, 0x00, 0xFA, 0x00, 0x64, 0x00, 0x5E, 0x01, 0x00, 0x00, 0x00, 0x00, 0x00, 0x00, 0x00, 0x00, 
  0x03, 0x00, 0x00, 0x00, 0x00, 0x00 };

// Set Nav Mode to Pedestrian
static const uint8_t setNavPedestrian[] = {
  0xB5, 0x62, 0x06, 0x24, 0x24, 0x00, 0xFF, 0xFF, 0x03, 0x03, 0x00, 0x00, 0x00, 0x00, 0x10, 0x27, 0x00, 0x00, 
  0x05, 0x00, 0xFA, 0x00, 0xFA, 0x00, 0x64, 0x00, 0x5E, 0x01, 0x00, 0x00, 0x00, 0x00, 0x00, 0x00, 0x00, 0x00, 
  0x03, 0x00, 0x00, 0x00, 0x00, 0x00 };

// Set Nav Mode to Automotive
static const uint8_t setNavAutomotive[] = {
  0xB5, 0x62, 0x06, 0x24, 0x24, 0x00, 0xFF, 0xFF, 0x04, 0x03, 0x00, 0x00, 0x00, 0x00, 0x10, 0x27, 0x00, 0x00, 
  0x05, 0x00, 0xFA, 0x00, 0xFA, 0x00, 0x64, 0x00, 0x5E, 0x01, 0x00, 0x00, 0x00, 0x00, 0x00, 0x00, 0x00, 0x00, 
  0x03, 0x00, 0x00, 0x00, 0x00, 0x00 };

// Set Nav Mode to Sea
static const uint8_t setNavSea[] = {
  0xB5, 0x62, 0x06, 0x24, 0x24, 0x00, 0xFF, 0xFF, 0x05, 0x03, 0x00, 0x00, 0x00, 0x00, 0x10, 0x27, 0x00, 0x00, 
  0x05, 0x00, 0xFA, 0x00, 0xFA, 0x00, 0x64, 0x00, 0x5E, 0x01, 0x00, 0x00, 0x00, 0x00, 0x00, 0x00, 0x00, 0x00, 
  0x03, 0x00, 0x00, 0x00, 0x00, 0x00 };

// Set Nav Mode to Airborne <1G
static const uint8_t setNavAir[] = {
  0xB5, 0x62, 0x06, 0x24, 0x24, 0x00, 0xFF, 0xFF, 0x06, 0x03, 0x00, 0x00, 0x00, 0x00, 0x10, 0x27, 0x00, 0x00, 
  0x05, 0x00, 0xFA, 0x00, 0xFA, 0x00, 0x64, 0x00, 0x5E, 0x01, 0x00, 0x00, 0x00, 0x00, 0x00, 0x00, 0x00, 0x00, 
  0x03, 0x00, 0x00, 0x00, 0x00, 0x00 };

// Set NMEA Config
// Set trackFilt to 1 to ensure course (COG) is always output
// Set Main Talker ID to 'GP' instead of 'GN'
static const uint8_t setNMEA[] = {
  0xb5, 0x62, 0x06, 0x17, 0x14, 0x00, 0x20, 0x40, 0x00, 0x02, 0x00, 0x00, 0x00, 0x00, 0x00, 0x01, 0x01, 0x01,
  0x00, 0x00, 0x00, 0x00, 0x00, 0x00, 0x00, 0x00 };
static const int len_setNMEA = 26;

// Set GNSS Config (Causes a restart of the M8!)
#ifdef GLONASS
// GPS + Galileo + GLONASS + SBAS
static const uint8_t setGNSS[] = {
  0xb5, 0x62, 0x06, 0x3e, 0x3c, 0x00,
  0x00, 0x20, 0x20, 0x07,
  0x00, 0x08, 0x10, 0x00, 0x01, 0x00, 0x01, 0x01,
  0x01, 0x01, 0x03, 0x00, 0x01, 0x00, 0x01, 0x01,
  0x02, 0x04, 0x08, 0x00, 0x01, 0x00, 0x01, 0x01,
  0x03, 0x08, 0x10, 0x00, 0x00, 0x00, 0x01, 0x01,
  0x04, 0x00, 0x08, 0x00, 0x00, 0x00, 0x01, 0x03,
  0x05, 0x00, 0x03, 0x00, 0x00, 0x00, 0x01, 0x05,
  0x06, 0x08, 0x0e, 0x00, 0x01, 0x00, 0x01, 0x01 };
/*
// GPS + Galileo + GLONASS
static const uint8_t setGNSS[] = {
  0xb5, 0x62, 0x06, 0x3e, 0x3c, 0x00,
  0x00, 0x20, 0x20, 0x07,
  0x00, 0x08, 0x10, 0x00, 0x01, 0x00, 0x01, 0x01,
  0x01, 0x01, 0x03, 0x00, 0x00, 0x00, 0x01, 0x01,
  0x02, 0x04, 0x08, 0x00, 0x01, 0x00, 0x01, 0x01,
  0x03, 0x08, 0x10, 0x00, 0x00, 0x00, 0x01, 0x01,
  0x04, 0x00, 0x08, 0x00, 0x00, 0x00, 0x01, 0x03,
  0x05, 0x00, 0x03, 0x00, 0x00, 0x00, 0x01, 0x05,
  0x06, 0x08, 0x0e, 0x00, 0x01, 0x00, 0x01, 0x01 };
*/
#else
// GPS + Galileo + BeiDou + SBAS
static const uint8_t setGNSS[] = {
  0xb5, 0x62, 0x06, 0x3e, 0x3c, 0x00,
  0x00, 0x20, 0x20, 0x07,
  0x00, 0x08, 0x10, 0x00, 0x01, 0x00, 0x01, 0x01,
  0x01, 0x01, 0x03, 0x00, 0x01, 0x00, 0x01, 0x01,
  0x02, 0x04, 0x08, 0x00, 0x01, 0x00, 0x01, 0x01,
  0x03, 0x08, 0x10, 0x00, 0x01, 0x00, 0x01, 0x01,
  0x04, 0x00, 0x08, 0x00, 0x00, 0x00, 0x01, 0x03,
  0x05, 0x00, 0x03, 0x00, 0x00, 0x00, 0x01, 0x05,
  0x06, 0x08, 0x0e, 0x00, 0x00, 0x00, 0x01, 0x01 };
/*
// GPS + Galileo + BeiDou
static const uint8_t setGNSS[] = {
  0xb5, 0x62, 0x06, 0x3e, 0x3c, 0x00,
  0x00, 0x20, 0x20, 0x07,
  0x00, 0x08, 0x10, 0x00, 0x01, 0x00, 0x01, 0x01,
  0x01, 0x01, 0x03, 0x00, 0x00, 0x00, 0x01, 0x01,
  0x02, 0x04, 0x08, 0x00, 0x01, 0x00, 0x01, 0x01,
  0x03, 0x08, 0x10, 0x00, 0x01, 0x00, 0x01, 0x01,
  0x04, 0x00, 0x08, 0x00, 0x00, 0x00, 0x01, 0x03,
  0x05, 0x00, 0x03, 0x00, 0x00, 0x00, 0x01, 0x05,
  0x06, 0x08, 0x0e, 0x00, 0x00, 0x00, 0x01, 0x01 };
*/
#endif
static const int len_setGNSS = 66;

// Set Navigation/Measurement Rate (CFG-RATE): set measRate to 250msec; align to UTC time
static const uint8_t setRATE[] = { 0xb5, 0x62, 0x06, 0x08, 0x06, 0x00, 0xfa, 0x00, 0x01, 0x00, 0x00, 0x00 };
// Set Navigation/Measurement Rate (CFG-RATE): set measRate to 250msec; align to GPS time
//static const uint8_t setRATE[] = { 0xb5, 0x62, 0x06, 0x08, 0x06, 0x00, 0xfa, 0x00, 0x01, 0x00, 0x01, 0x00 };
// Set Navigation/Measurement Rate (CFG-RATE): set measRate to 1000msec; align to UTC time
static const uint8_t setRATE_1Hz[] = { 0xb5, 0x62, 0x06, 0x08, 0x06, 0x00, 0xe8, 0x03, 0x01, 0x00, 0x00, 0x00 };
// Set Navigation/Measurement Rate (CFG-RATE): set measRate to 10000msec; align to UTC time
static const uint8_t setRATE_10s[] = { 0xb5, 0x62, 0x06, 0x08, 0x06, 0x00, 0x10, 0x27, 0x01, 0x00, 0x00, 0x00 };
static const uint8_t len_setRATE = 12;

// Set RXM-RAWX Message Rate: once per measRate
static const uint8_t setRAWX[] = { 0xb5, 0x62, 0x06, 0x01, 0x03, 0x00, 0x02, 0x15, 0x01 };
// Set RXM-RAWX Message Rate: off
static const uint8_t setRAWXoff[] = { 0xb5, 0x62, 0x06, 0x01, 0x03, 0x00, 0x02, 0x15, 0x00 };
static const int len_setRAWX = 9;

// Set RXM-SFRBX Message Rate: once per measRate
static const uint8_t setSFRBX[] = { 0xb5, 0x62, 0x06, 0x01, 0x03, 0x00, 0x02, 0x13, 0x01 };
// Set RXM-SFRBX Message Rate: off
static const uint8_t setSFRBXoff[] = { 0xb5, 0x62, 0x06, 0x01, 0x03, 0x00, 0x02, 0x13, 0x00 };
static const int len_setSFRBX = 9;

// Set TIM-TM2 Message Rate: once per measRate
static const uint8_t setTIM[] = { 0xb5, 0x62, 0x06, 0x01, 0x03, 0x00, 0x0d, 0x03, 0x01 };
// Set TIM-TM2 Message Rate: off
static const uint8_t setTIMoff[] = { 0xb5, 0x62, 0x06, 0x01, 0x03, 0x00, 0x0d, 0x03, 0x00 };
static const int len_setTIM = 9;

// Set port configuration - disable or enable UBX output messages on the UART
static const uint8_t setUBX[] = {
  0xb5, 0x62, 0x06, 0x00, 0x14, 0x00, 0x01, 0x00, 0x00, 0x00, 0xc0, 0x08, 0x00, 0x00, 0x00, 0xc2, 0x01, 0x00,
  0x03, 0x00, 0x03, 0x00, 0x00, 0x00, 0x00, 0x00 };
static const uint8_t setUBXoff[] = {
  0xb5, 0x62, 0x06, 0x00, 0x14, 0x00, 0x01, 0x00, 0x00, 0x00, 0xc0, 0x08, 0x00, 0x00, 0x00, 0xc2, 0x01, 0x00,
  0x03, 0x00, 0x02, 0x00, 0x00, 0x00, 0x00, 0x00 };
static const int len_setUBX = 26;
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
void loop() // run over and over again
{
  switch(loop_step) {
    case init: {
      // read data from the GNSS
      char c = GPS.read();
      // if you want to debug, this is a good time to do it!
      if (GPSECHO)
        if (c) Serial.print(c);
      // if a sentence is received, we can check the checksum, parse it...
      if (GPS.newNMEAreceived()) {
        if (!GPS.parse(GPS.lastNMEA())) // this also sets the newNMEAreceived() flag to false
          break; // we can fail to parse a sentence in which case we should just wait for another
    
#ifdef DEBUG
        Serial.print("\nTime: ");
        Serial.print(GPS.hour, DEC); Serial.print(':');
        Serial.print(GPS.minute, DEC); Serial.print(':');
        Serial.print(GPS.seconds, DEC); Serial.print('.');
        Serial.println(GPS.milliseconds);
        Serial.print("Date: ");
        Serial.print(GPS.day, DEC); Serial.print('/');
        Serial.print(GPS.month, DEC); Serial.print("/20");
        Serial.println(GPS.year, DEC);
        Serial.print("Fix: "); Serial.print((int)GPS.fix);
        Serial.print(" Quality: "); Serial.println((int)GPS.fixquality);
        if (GPS.fix) {
          Serial.print("Location: ");
          Serial.print(GPS.latitude, 4); Serial.print(GPS.lat);
          Serial.print(", ");
          Serial.print(GPS.longitude, 4); Serial.println(GPS.lon);
          Serial.print("Speed (knots): "); Serial.println(GPS.speed);
          Serial.print("Angle: "); Serial.println(GPS.angle);
          Serial.print("Altitude: "); Serial.println(GPS.altitude);
          Serial.print("Satellites: "); Serial.println((int)GPS.satellites);
          Serial.print("HDOP: "); Serial.println(GPS.HDOP);
        }
#endif
  
        // read battery voltage
        vbat = analogRead(A7) * (2.0 * 3.3 / 1023.0);
#ifdef DEBUG
        Serial.print("Battery(V): ");
        Serial.println(vbat, 2);
#endif
      
        // indicate GNSS fix
        if (GPS.fix) {
#ifndef NoLED
#ifdef NeoPixel
          LED_cyan(); // Set NeoPixel to cyan
#else
          digitalWrite(GreenLED, HIGH);
#endif
#endif
          // increment valfix and cap at maxvalfix
          // don't do anything fancy in terms of decrementing valfix as we want to keep logging even if the fix is lost
          valfix += 1;
          if (valfix > maxvalfix) valfix = maxvalfix;
        }
        else {
#ifndef NoLED
#ifdef NeoPixel
          LED_dim_cyan(); // Set NeoPixel to dim cyan
#else
          digitalWrite(GreenLED, LOW); // Turn green LED off
#endif
#endif
        }
  
        if (valfix == maxvalfix) { // wait until we have enough valid fixes
          
          // Set and start the RTC
          alarmFlag = false; // Make sure alarm flag is clear
          rtc.begin(); // Start the RTC
          rtc.setTime(GPS.hour, GPS.minute, GPS.seconds); // Set the time
          rtc.setDate(GPS.day, GPS.month, GPS.year); // Set the date
          rtc.setAlarmSeconds(0); // Set RTC Alarm Seconds to zero
          uint8_t nextAlarmMin = ((GPS.minute+INTERVAL)/INTERVAL)*INTERVAL; // Calculate next alarm minutes
          nextAlarmMin = nextAlarmMin % 60; // Correct hour rollover
          rtc.setAlarmMinutes(nextAlarmMin); // Set RTC Alarm Minutes
          rtc.enableAlarm(rtc.MATCH_MMSS); // Alarm Match on minutes and seconds
          rtc.attachInterrupt(alarmMatch); // Attach alarm interrupt

          // check if voltage is > LOWBAT(V), if not then don't try to log any data
          if (vbat < LOWBAT) {
            Serial.println("Low Battery!");
            break;
          }

          // Disable the GPGGA and GPRMC messages; set the RAWX measurement rate
          GPS.sendCommand("$PUBX,40,GGA,0,0,0,0*5A");  // Disable GGA
          delay(100);
          GPS.sendCommand("$PUBX,40,RMC,0,0,0,0*47");  // Disable RMC
          delay(100);
          sendUBX(setRATE, len_setRATE); // Set Navigation/Measurement Rate
          delay(1100); // Wait
          while(Serial1.available()){Serial1.read();} // Flush RX buffer to clear UBX acknowledgement
          
          // Now that Serial1 should be idle and the buffer empty, start TC3 interrupts to copy all new data into SerialBuffer
          // Set the timer interval to 10 * 10 / 230400 = 0.000434 secs (10 bytes * 10 bits (1 start, 8 data, 1 stop) at 230400 baud)
          startTimerInterval(0.000434); 
          
          loop_step = start_rawx; // start rawx messages
        }
      }
    }
    break;

    // (Re)Start RAWX messages
    case start_rawx: {
      sendUBX(setRAWX, len_setRAWX); // Set RXM-RAWX message rate
      sendUBX(setSFRBX, len_setSFRBX); // Set RXM-SFRBX message rate
      sendUBX(setTIM, len_setTIM); // Set TIM-TM2 message rate

      bufferPointer = 0; // (Re)initialise bufferPointer

      while (SerialBuffer.available() < 30) { ; } // Wait for three UBX acknowledgements' worth of data (3 x 10 = 30 bytes)
      
      for (int x=0;x<3;x++) { // Check ten bytes three times
        for (int y=0;y<10;y++) { // Get ten bytes
          serBuffer[bufferPointer] = SerialBuffer.read_char(); // Add a character to serBuffer
          bufferPointer++; // Increment the pointer   
        }
        // Now check if these bytes were an acknowledgement
        if ((serBuffer[bufferPointer - 10] == 0xB5) and (serBuffer[bufferPointer - 9] == 0x62) and (serBuffer[bufferPointer - 8] == 0x05)) {
          // This must be an acknowledgement so simply ignore it and decrement bufferPointer by 10
          bufferPointer -= 10;
        }
      }

      loop_step = open_file; // start logging rawx data
    }
    break;

    // Open the log file
    case open_file: {
      
      // Get the RTC time and date
      uint8_t RTCseconds = rtc.getSeconds();
      uint8_t RTCminutes = rtc.getMinutes();
      uint8_t RTChours = rtc.getHours();
      uint8_t RTCday = rtc.getDay();
      uint8_t RTCmonth = rtc.getMonth();
      uint8_t RTCyear = rtc.getYear();
      
      // Do the divides to convert date and time to char
      char secT = RTCseconds/10 + '0';
      char secU = RTCseconds%10 + '0';
      char minT = RTCminutes/10 + '0';
      char minU = RTCminutes%10 + '0';
      char hourT = RTChours/10 + '0';
      char hourU = RTChours%10 + '0';
      char dayT = RTCday/10 +'0';
      char dayU = RTCday%10 +'0';
      char monT = RTCmonth/10 +'0';
      char monU = RTCmonth%10 +'0';
      char yearT = RTCyear/10 +'0';
      char yearU = RTCyear%10 +'0';
  
      // filename is limited to 8.3 characters so use format: YYYYMMDD/r_HHMMSS.ubx or YYYYMMDD/b_HHMMSS.ubx
      rawx_filename[2] = yearT;
      rawx_filename[3] = yearU;
      rawx_filename[4] = monT;
      rawx_filename[5] = monU;
      rawx_filename[6] = dayT;
      rawx_filename[7] = dayU;
      rawx_filename[11] = hourT;
      rawx_filename[12] = hourU;
      rawx_filename[13] = minT;
      rawx_filename[14] = minU;
      rawx_filename[15] = secT;
      rawx_filename[16] = secU;
      
      dirname[2] = yearT;
      dirname[3] = yearU;
      dirname[4] = monT;
      dirname[5] = monU;
      dirname[6] = dayT;
      dirname[7] = dayU;

      // flash red LED to indicate SD write (leave on if an error occurs)
      // or flash NeoPixel green
#ifndef NoLED
#ifdef NeoPixel
#ifndef NoLogLED
      LED_green(); // Set the NeoPixel to green
#else
      LED_off(); // Turn NeoPixel off if NoLogLED
#endif
#else
#ifndef NoLogLED
      digitalWrite(RedLED, HIGH); // Turn the red LED on to indicate SD card write
#else
      digitalWrite(RedLED, LOW); // Turn the red LED off for NoLogLED
      digitalWrite(GreenLED, LOW); // Turn the green LED off for NoLogLED
#endif
#endif
#endif

     // try to create subdirectory (even if it exists already)
      sd.mkdir(dirname);
      
      // Open the rawx file for fast writing
      if (rawx_dataFile.open(rawx_filename, O_CREAT | O_WRITE | O_EXCL)) {
        Serial.print("Logging to ");
        Serial.println(rawx_filename);
      }
      // if the file isn't open, pop up an error:
      else {
        Serial.println("Panic!! Error opening RAWX file!");
        Serial.println("Waiting for reset...");
#ifndef NoLED
#ifdef NeoPixel
      LED_red(); // Set the NeoPixel to red to indicate a problem
#else
      digitalWrite(RedLED, HIGH); // Turn the red LED on to indicate a problem
#endif
#endif
        // don't do anything more:
        while(1);
      }

#ifdef DEBUG
      // Set the log file creation time
      if (!rawx_dataFile.timestamp(T_CREATE, (RTCyear+2000), RTCmonth, RTCday, RTChours, RTCminutes, RTCseconds)) {
        Serial.println("Warning! Could not set file create timestamp!");
      }
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

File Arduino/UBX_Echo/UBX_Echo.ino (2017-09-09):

// UBX Echo

// Simple serial echo for the u-blox NEO-M8T GNSS FeatherWing
// https://github.com/PaulZC/NEO-M8T_GNSS_FeatherWing

// ** Changes the NEO-M8T Baud rate from 9600 to 115200 **
// (to allow fast RAWX logging)

// Designed to run on the Adafruit Feather M0 Adalogger
// https://www.adafruit.com/product/2796
// https://learn.adafruit.com/adafruit-feather-m0-adalogger

// Code is based on:
// https://github.com/adafruit/Adafruit_GPS/tree/master/examples/GPS_HardwareSerial_EchoTest

void setup()
{
  Serial1.begin(9600); // Start off using 9600 Baud to talk to the NEO-M8T
  Serial.begin(115200); // Use 115200 baud to talk to the PC

  // give the NEO-M8T time to power up and/or give the user time to open a serial monitor
  // by flashing the LEDs for 10 seconds
  pinMode(13, OUTPUT); // Red LED
  pinMode(8, OUTPUT); // Green LED
  // flash red and green LEDs on reset
  for (int i=0; i <= 25; i++) {
    digitalWrite(13, HIGH);
    delay(200);
    digitalWrite(13, LOW);
    digitalWrite(8, HIGH);
    delay(200);
    digitalWrite(8, LOW);
  }

  // Wait for user to run python script or open serial monitor
  // Comment out if you want the code to run without waiting
  //while (!Serial);

  // Change the NEO-M8T UART Baud rate to 115200
  // (DDC (I2C) and SPI rates can be set independantly if required)
  // Allow both NMEA and UBX protocols (but not RTCM)
  // Disable autobauding
  Serial1.write("$PUBX,41,1,0003,0003,115200,0*1C\r\n");

  // Allow time for Baud rate change
  delay(1000);

  // Restart serial communications at 115200 Baud
  Serial1.begin(115200);
}
     
void loop() // run over and over again
{
  if (Serial.available()) {
    digitalWrite(13, HIGH); // Flash red LED
    char c = Serial.read();
    Serial1.write(c);
    digitalWrite(13, LOW);
  }
  if (Serial1.available()) {
    digitalWrite(8, HIGH); // Flash green LED
    char c = Serial1.read();
    Serial.write(c);
    digitalWrite(8, LOW);
  }  
}

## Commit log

2017-08-14 Initial commit
    Initial commit. PCB is just about ready for testing. Photos and Arduino
    code to follow.
    [NEO-M8T GNSS FeatherWing.brd, NEO-M8T GNSS FeatherWing.sch]
2017-08-14 Added initial Arduino and Python code
2017-08-14 Groundplane improvements
    [NEO-M8T GNSS FeatherWing.brd, NEO-M8T GNSS FeatherWing.sch]
2017-08-16 Added SCL and SDA pullups
    Managed to squeeze in pull-up resistors for SCL and SDA.
    [NEO-M8T GNSS FeatherWing.brd, NEO-M8T GNSS FeatherWing.sch]
2017-08-16 Added images of the PCB
2017-08-17 Added the BOM
2017-08-17 Minor tweaks
    [NEO-M8T GNSS FeatherWing.brd, NEO-M8T GNSS FeatherWing.sch]
2017-08-19 Draft RAWX_Logger Arduino code added
2017-09-09 Substantial update after first successful PCB tests
2017-09-10 Fixed the buffer overrun!
    [RAWX_Logger.ino]
2017-09-10 Added a close-up of the stop switch
2017-09-14 Added image of EN switch
2017-09-14 Updated the image of the EN switch
2017-09-17 Now logs RAWX, SFRBX and TM2 messages
    Updated the Arduino and Python code so that they log RXM-RAWX, RXM-SFRBX
    and TIM-TM2 messages, not just RXM-RAWX.
2017-09-19 Updated NEO-M8T_GNSS_RAWX_Logger.py
    Updated NEO-M8T_GNSS_RAWX_Logger.py. Code now creates a 'clean' log
    file: the final received packet(s) are logged to file correctly.
    [NEO-M8T_GNSS_RAWX_Logger.py]
2017-09-19 Updated the .brd. Now uses smaller vias.
    Updated the .brd. Now uses smaller vias which will be covered with
    solder resist.
    [NEO-M8T GNSS FeatherWing.brd]
2017-09-20 Excluded the vias from the stop layers
    [NEO-M8T GNSS FeatherWing.brd]
2018-03-06 RAWX_Logger .ubx files now have correct dates and times
    [RAWX_Logger.ino]
2018-03-06 Updates and a bugfix
    The .ubx log files now have the correct date and time for creation and
    last update. Fixed a rookie error in the RTC ISR - moved the
    next-alarm-time code into the main loop as this was causing occasional
    serial data loss during file changes.
    [RAWX_Logger_2.ino]
2018-03-20 Added the PCB design for the SMA antenna.
    [NEO-M8T GNSS FeatherWing.brd, NEO-M8T GNSS FeatherWing.sch]
2018-03-20 Added the PCB design for an SMA antenna.
